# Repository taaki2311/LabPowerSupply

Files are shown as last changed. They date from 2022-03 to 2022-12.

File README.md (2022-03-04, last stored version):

# ECE_492-3_Topic_1

This git repository is for ECE/RS 492/3 Topic 1: Lab Power Supply in Spring to Fall 2022.

## Getting started

To make it easy for you to get started with GitLab, here's a list of recommended next steps.

Already a pro? Just edit this README.md and make it your own. Want to make it easy? [Use the template at the bottom](#editing-this-readme)!

## Add your files

- [ ] [Create](https://docs.gitlab.com/ee/user/project/repository/web_editor.html#create-a-file) or [upload](https://docs.gitlab.com/ee/user/project/repository/web_editor.html#upload-a-file) files
- [ ] [Add files using the command line](https://docs.gitlab.com/ee/gitlab-basics/add-file.html#add-a-file-using-the-command-line) or push an existing Git repository with the following command:

```
cd existing_repo
git remote add origin https://git.gmu.edu/tsingh8/ece_492-3_topic_1.git
git branch -M main
git push -uf origin main
```

## Integrate with your tools

- [ ] [Set up project integrations](https://git.gmu.edu/tsingh8/ece_492-3_topic_1/-/settings/integrations)

## Collaborate with your team

- [ ] [Invite team members and collaborators](https://docs.gitlab.com/ee/user/project/members/)
- [ ] [Create a new merge request](https://docs.gitlab.com/ee/user/project/merge_requests/creating_merge_requests.html)
- [ ] [Automatically close issues from merge requests](https://docs.gitlab.com/ee/user/project/issues/managing_issues.html#closing-issues-automatically)
- [ ] [Enable merge request approvals](https://docs.gitlab.com/ee/user/project/merge_requests/approvals/)
- [ ] [Automatically merge when pipeline succeeds](https://docs.gitlab.com/ee/user/project/merge_requests/merge_when_pipeline_succeeds.html)

## Test and Deploy

Use the built-in continuous integration in GitLab.

- [ ] [Get started with GitLab CI/CD](https://docs.gitlab.com/ee/ci/quick_start/index.html)
- [ ] [Analyze your code for known vulnerabilities with Static Application Security Testing(SAST)](https://docs.gitlab.com/ee/user/application_security/sast/)
- [ ] [Deploy to Kubernetes, Amazon EC2, or Amazon ECS using Auto Deploy](https://docs.gitlab.com/ee/topics/autodevops/requirements.html)
- [ ] [Use pull-based deployments for improved Kubernetes management](https://docs.gitlab.com/ee/user/clusters/agent/)
- [ ] [Set up protected environments](https://docs.gitlab.com/ee/ci/environments/protected_environments.html)

***

# Editing this README

When you're ready to make this README your own, just edit this file and use the handy template below (or feel free to structure it however you want - this is just a starting point!).  Thank you to [makeareadme.com](https://www.makeareadme.com/) for this template.

## Suggestions for a good README
Every project is different, so consider which of these sections apply to yours. The sections used in the template are suggestions for most open source projects. Also keep in mind that while a README can be too long and detailed, too long is better than too short. If you think your README is too long, consider utilizing another form of documentation rather than cutting out information.

## Name
Choose a self-explaining name for your project.

## Description
Let people know what your project can do specifically. Provide context and add a link to any reference visitors might be unfamiliar with. A list of Features or a Background subsection can also be added here. If there are alternatives to your project, this is a good place to list differentiating factors.

## Badges
On some READMEs, you may see small images that convey metadata, such as whether or not all the tests are passing for the project. You can use Shields to add some to your README. Many services also have instructions for adding a badge.

## Visuals
Depending on what you are making, it can be a good idea to include screenshots or even a video (you'll frequently see GIFs rather than actual videos). Tools like ttygif can help, but check out Asciinema for a more sophisticated method.

## Installation
Within a particular ecosystem, there may be a common way of installing things, such as using Yarn, NuGet, or Homebrew. However, consider the possibility that whoever is reading your README is a novice and would like more guidance. Listing specific steps helps remove ambiguity and gets people to using your project as quickly as possible. If it only runs in a specific context like a particular programming language version or operating system or has dependencies that have to be installed manually, also add a Requirements subsection.

## Usage
Use examples liberally, and show the expected output if you can. It's helpful to have inline the smallest example of usage that you can demonstrate, while providing links to more sophisticated examples if they are too long to reasonably include in the README.

## Support
Tell people where they can go to for help. It can be any combination of an issue tracker, a chat room, an email address, etc.

## Roadmap
If you have ideas for releases in the future, it is a good idea to list them in the README.

## Contributing
State if you are open to contributions and what your requirements are for accepting them.

For people who want to make changes to your project, it's helpful to have some documentation on how to get started. Perhaps there is a script that they should run or some environment variables that they need to set. Make these steps explicit. These instructions could also be useful to your future self.

You can also document commands to lint the code or run tests. These steps help to ensure high code quality and reduce the likelihood that the changes inadvertently break something. Having instructions for running tests is especially helpful if it requires external setup, such as starting a Selenium server for testing in a browser.

## Authors and acknowledgment
Show your appreciation to those who have contributed to the project.

## License
For open source projects, say how it is licensed.

## Project status
If you have run out of energy or time for your project, put a note at the top of the README saying that development has slowed down or stopped completely. Someone may choose to fork your project or volunteer to step in as a maintainer or owner, allowing your project to keep going. You can also make an explicit request for maintainers.

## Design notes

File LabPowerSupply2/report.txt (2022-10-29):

Plotted to 'C:\Users\Krotain\Documents\git\493\ece_492-3_topic_1\LabPowerSupply\Gerbers\LabPowerSupply-Fsig_Cu.gbr'.
Plotted to 'C:\Users\Krotain\Documents\git\493\ece_492-3_topic_1\LabPowerSupply\Gerbers\LabPowerSupply-pwr_Cu.gbr'.
Plotted to 'C:\Users\Krotain\Documents\git\493\ece_492-3_topic_1\LabPowerSupply\Gerbers\LabPowerSupply-gnd_Cu.gbr'.
Plotted to 'C:\Users\Krotain\Documents\git\493\ece_492-3_topic_1\LabPowerSupply\Gerbers\LabPowerSupply-Bsig_Cu.gbr'.
Plotted to 'C:\Users\Krotain\Documents\git\493\ece_492-3_topic_1\LabPowerSupply\Gerbers\LabPowerSupply-F_Paste.gbr'.
Plotted to 'C:\Users\Krotain\Documents\git\493\ece_492-3_topic_1\LabPowerSupply\Gerbers\LabPowerSupply-B_Paste.gbr'.
Plotted to 'C:\Users\Krotain\Documents\git\493\ece_492-3_topic_1\LabPowerSupply\Gerbers\LabPowerSupply-F_Silkscreen.gbr'.
Plotted to 'C:\Users\Krotain\Documents\git\493\ece_492-3_topic_1\LabPowerSupply\Gerbers\LabPowerSupply-B_Silkscreen.gbr'.
Plotted to 'C:\Users\Krotain\Documents\git\493\ece_492-3_topic_1\LabPowerSupply\Gerbers\LabPowerSupply-F_Mask.gbr'.
Plotted to 'C:\Users\Krotain\Documents\git\493\ece_492-3_topic_1\LabPowerSupply\Gerbers\LabPowerSupply-B_Mask.gbr'.
Plotted to 'C:\Users\Krotain\Documents\git\493\ece_492-3_topic_1\LabPowerSupply\Gerbers\LabPowerSupply-Edge_Cuts.gbr'.
Created Gerber job file 'C:\Users\Krotain\Documents\git\493\ece_492-3_topic_1\LabPowerSupply\Gerbers\LabPowerSupply-job.gbrjob'.
Info: Done.

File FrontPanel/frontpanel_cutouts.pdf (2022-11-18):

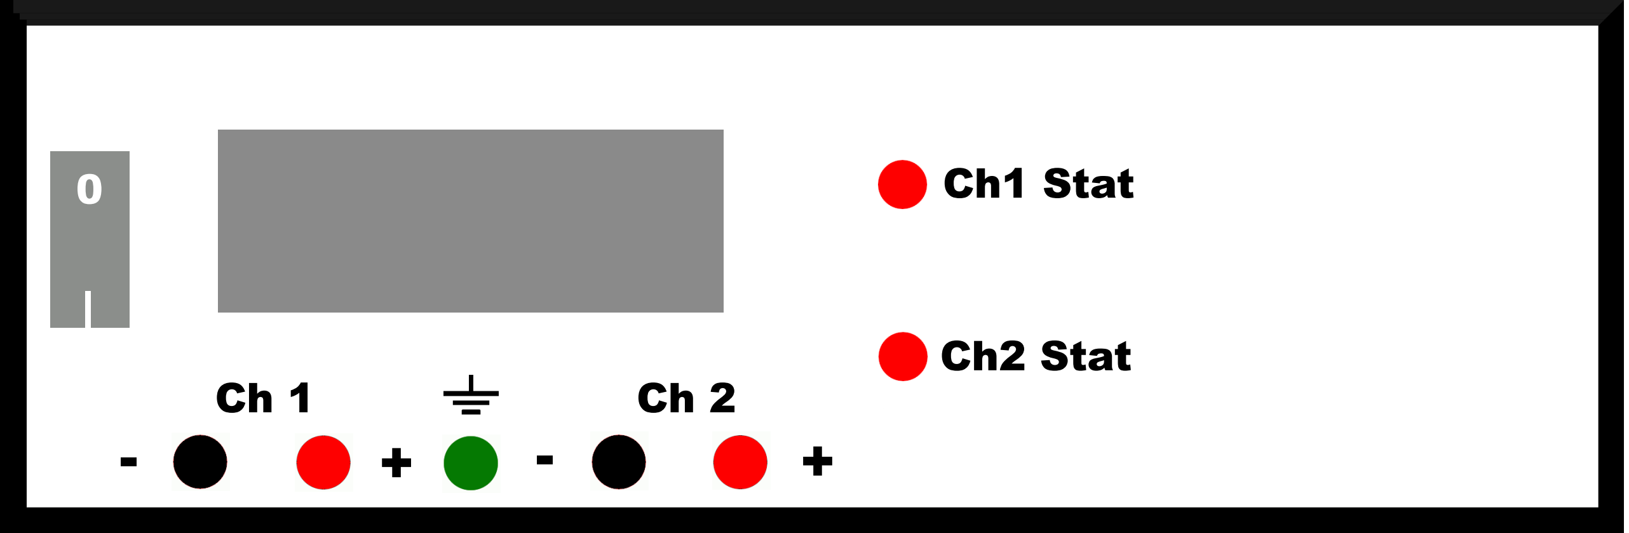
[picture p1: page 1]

- | + | - | +

0

Ch 1 | Ch 2

Ch2 Stat

Ch1 Stat

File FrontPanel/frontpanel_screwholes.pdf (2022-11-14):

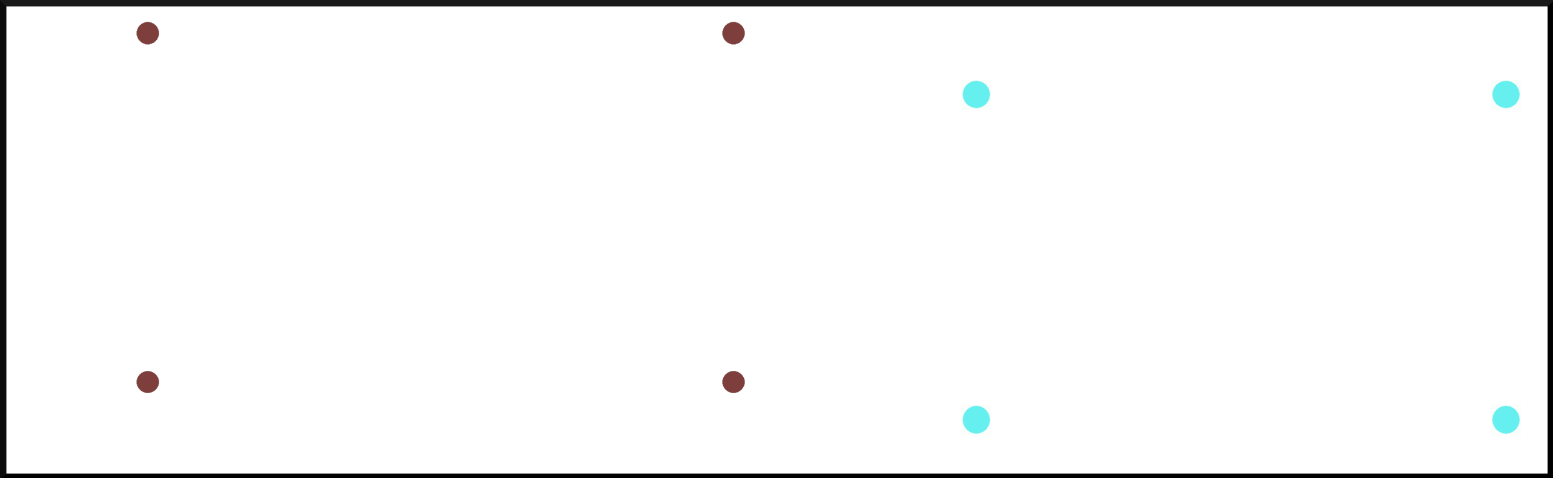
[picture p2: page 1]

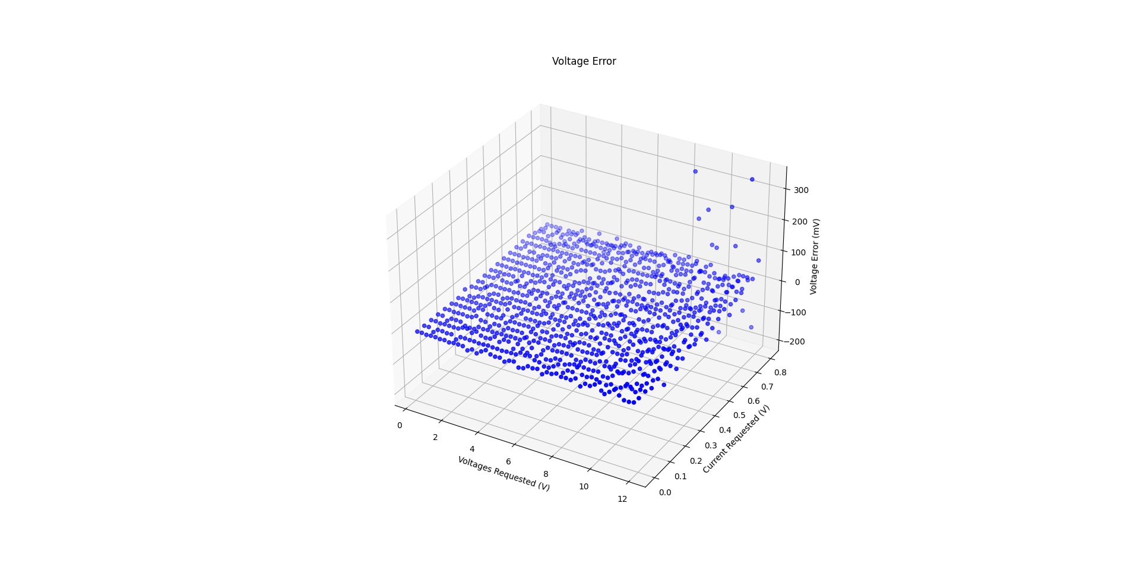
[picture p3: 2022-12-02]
Plots/voltage_plot.png

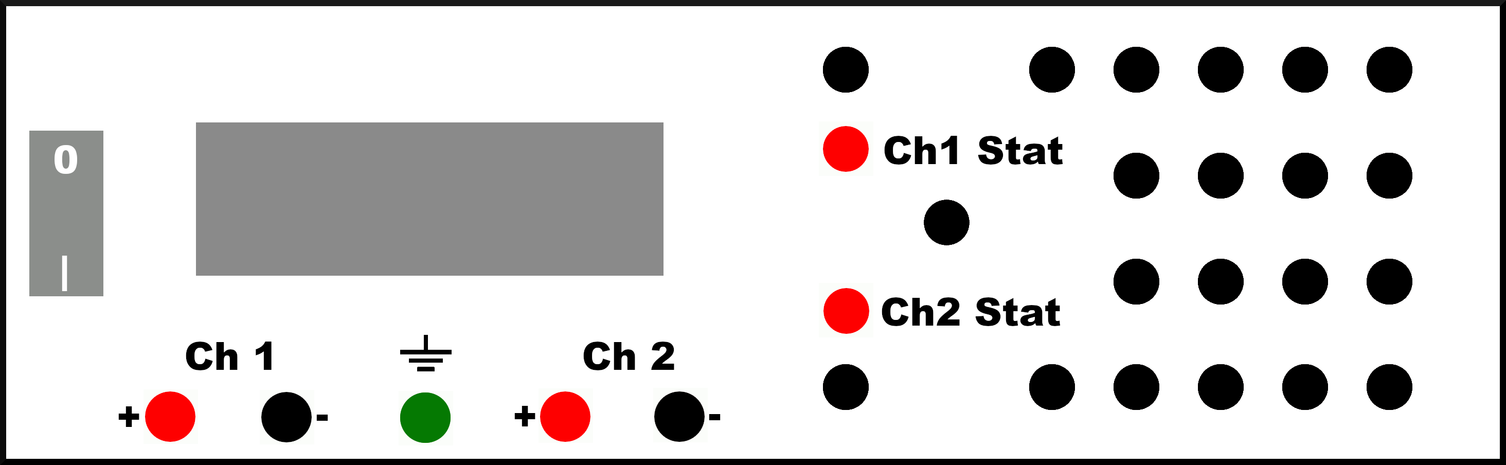
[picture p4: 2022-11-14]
FrontPanel/frontpanel_cutouts.png

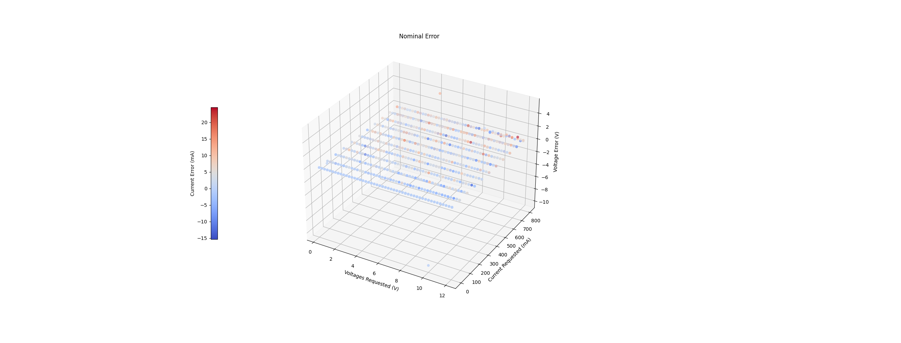
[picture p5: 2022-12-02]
Plots/combined_plot.png

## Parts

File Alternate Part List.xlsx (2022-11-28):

Part(*=Similar) | Quantity | $/1 | $/1000 | Total | Value | Tolerance | Size/Package | Link | Running Total
PMEG3020CEP,115 | 8 | 0.49 | 0.152 | 1.216 | 2A 30V | n/a | SOD-128-2 | https://www.digikey.com/en/products/detail/nexperia-usa-inc/PMEG3020CEP-115/2119870 | 106.07417
GS2A-LTP | 10 | 0.4 | 0.079 | 0.79 | 2A 50V | n/a | DO-214AC-2 | https://www.mouser.com/ProductDetail/Micro-Commercial-Components-MCC/GS2A-LTP
UVR1E682MHD | 4 | 2.47 | 1.01 | 4.04 | 6.8mF | 20% | 18x35.5x7.5mm | https://www.mouser.com/ProductDetail/Nichicon/UVR1E682MHD?qs=sGAEpiMZZMvwFf0viD3Y3UQjCBAmXhuzNEsRvpP9m3M%3D
UVZ1E102MPD | 2 | 0.78 | 0.22874 | 0.45748 | 1mF | 20% | 10x20x5mm | https://www.digikey.com/en/products/detail/nichicon/UVZ1E102MPD/589046
A750KK107M1EAAE040 | 2 | 0.62 | 0.18 | 0.36 | 100uf | 20% | 8x8x3.5mm Rad | https://www.mouser.com/ProductDetail/KEMET/A750KK107M1EAAE040?qs=M6jHmRuQorXMeyrpWCoqNA%3D%3D
CL32A226KAJNNNE | 12 | 0.44 | 0.12888 | 1.54656 | 22uf | 10% | 1210 | https://www.digikey.com/en/products/detail/samsung-electro-mechanics/CL32A226KAJNNNE/3886759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
CL31A106MAHNNNE | 6 | 0.19 | 0.03713 | 0.22278 | 10uf | 10% | 1206 | https://www.digikey.com/en/products/detail/samsung-electro-mechanics/CL31A106MAHNNNE/3886839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
CL21A475KAQNNNG | 2 | 0.1 | 0.01984 | 0.03968 | 4.7uf | 10% | 0805 | https://www.digikey.com/en/products/detail/samsung-electro-mechanics/CL21A475KAQNNNG/3894439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
CL21A225KAFNNNG | 2 | 0.12 | 0.02331 | 0.04662 | 2.2uf | 10% | 0805 | https://www.digikey.com/en/products/detail/samsung-electro-mechanics/CL21A225KAFNNNG/3894427
CL10A105KA8NNNC | 9 | 0.1 | 0.00786 | 0.07074 | 1uf | 10% | 0603 | https://www.digikey.com/en/products/detail/samsung-electro-mechanics/CL10A105KA8NNNC/3886760
CL10B104KB8NNWC | 17 | 0.1 | 0.00467 | 0.07939 | 100nf | 10% | 0603 | https://www.digikey.com/en/products/detail/samsung-electro-mechanics/CL10B104KB8NNWC/3887593
CL10B223KB8NNNC | 2 | 0.1 | 0.00819 | 0.01638 | 22nf | 10% | 0603 | https://www.digikey.com/en/products/detail/samsung-electro-mechanics/CL10B223KB8NNNC/3886762
0603B221K500CT | 2 | 0.1 | 0.00667 | 0.01334 | 220pf | 10% | 0603 | https://www.digikey.com/en/products/detail/walsin-technology-corporation/0603B221K500CT/9354904
CML0603C0G200JT50V | 6 | 0.1 | 0.00889 | 0.05334 | 20pf | 5% | 0603 | https://www.digikey.com/en/products/detail/stackpole-electronics-inc/CML0603C0G200JT50V/10659974
SN74HC04DBRG4 | 2 | 0.46 | 0.142 | 0.284 | n/a | n/a | SSOP-14 | https://www.mouser.com/ProductDetail/Texas-Instruments/SN74HC04DBRG4?qs=XQzc%252BbSrk58m%252Bx0j7t4flA%3D%3D
6N137S-TA1 | 2 | 0.84 | 0.283 | 0.566 | n/a | n/a | SMD-8 | https://www.mouser.com/ProductDetail/Lite-On/6N137S-TA1?qs=PByDJ0nQNwrChwHSrgNi1w%3D%3D
LM324DR | 2 | 0.38 | 0.117 | 0.234 | n/a | n/a | SOIC-14 | https://www.mouser.com/ProductDetail/Texas-Instruments/LM324DR?qs=KaAwwOlwaps1n%2FWkYDapEg%3D%3D
INA180A1 | 2 | 0.51 | 0.19642 | 0.39284 | n/a | n/a | SOT-23-5 | https://www.digikey.com/en/products/detail/texas-instruments/INA180A1IDBVR/8132986
PJA3404_R1_00001 | 6 | 0.38 | 0.08197 | 0.49182 | n/a | n/a | SOT-23-5 | https://www.digikey.com/en/products/detail/panjit-international-inc/PJA3404-R1-00001/14660647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
FMMT495 | 2 | 0.4 | 0.124 | 0.248 | n/a | n/a | SOT-23-3 | https://www.mouser.com/ProductDetail/Diodes-Incorporated/FMMT495TA?qs=YwPsRIUVAOcuV4OIGitV8Q%3D%3D
PTS181224V075 | 2 | 0.59 | 0.285 | 3083et | 0.2Ohm | n/a | 1812 | https://www.mouser.com/ProductDetail/576-1812L110-24DR
AP63205WU-7 | 2 | 0.91 | 0.38737 | 0.77474 | n/a | n/a | TSOT-26-6 | https://www.digikey.com/en/products/detail/diodes-incorporated/AP63205WU-7/9858424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
LP2950CDT-3.3RKG | 2 | 0.75 | 0.32139 | 0.64278 | n/a | n/a | TO-252-3 | https://www.digikey.com/en/products/detail/onsemi/LP2950CDT-3-3RKG/1476904
LT3080EDD | 2 | 6.41 | 7.29 | 14.58 | n/a | n/a | DFN-8 | https://www.mouser.com/ProductDetail/Analog-Devices/LT3080EDD-1TRPBF?qs=hVkxg5c3xu%2F3H2mzAs8Yaw%3D%3D
L6902D | 2 | 3.44 | 1.96 | 3.92 | n/a | n/a | SOIC-8 | https://www.mouser.com/ProductDetail/STMicroelectronics/L6902D?qs=Yc96klrMi5L2iIsse6YmdQ%3D%3D
Enclosure | 1 | 15.95 | 12.95 | 12.95 | n/a | n/a | n/a | https://www.jameco.com/z/SY0207-R-Jameco-Valuepro-Metal-Enclosure-2-Piece-7-5-x-9-8-x-3-2-Gloss-Black-and-Ivory_209358.html
20x4 Character Display | 1 | 12.95 | 10.95 | 10.95 | n/a | n/a | n/a | https://www.jameco.com/z/SIC2004A-BLWIT-Jameco-Valuepro-20x4-Character-LCD-Module-Parallel-Display-with-I2C-Module-Blue-Backlight-for-Arduino_2304015.html
USB4125-GF-A | 1 | 0.65 | 0.332 | 0.332 | n/a | n/a | n/a | https://www.mouser.com/ProductDetail/GCT/USB4125-GF-A?qs=KUoIvG%2F9IlaIQ4zBJ6gLeA%3D%3D
STM32L152RBT6A | 1 | 8.06 | 4.51 | 4.51 | n/a | n/a | LQFP-64 | https://www.mouser.com/ProductDetail/STMicroelectronics/STM32L152RBT6A?qs=DqCdCwOw4%2F646g2lv17dkw%3D%3D
STM32L100C6U6A | 1 | 5.57 | 2.95 | 2.95 | n/a | n/a | UFQFPN-48 | https://www.mouser.com/ProductDetail/STMicroelectronics/STM32L100C6U6A?qs=9MuLHSklicr37J4PyR0bYg%3D%3D
ATS08ASM-1 | 2 | 0.29 | 0.153 | 0.306 | 8MHz | n/a | HC-49/US-SM | https://www.mouser.com/ProductDetail/CTS-Electronic-Components/ATS08ASM-1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
FS24-1500-C2 | 1 | 17.1 | 14.38 | 14.38 | n/a | n/a | Big | https://www.mouser.com/ProductDetail/553-FS24-1500-C2
CR75NP-220KC | 2 | 1.08 | 0.4956 | 0.9912 | 22uh | 10% | Nonstandard | https://www.digikey.com/en/products/detail/sumida-america-inc/CR75NP-220KC/1059617
CDMC6D28NP-4R7MC | 2 | 1.25 | 0.57288 | 1.14576 | 4.7uh | 20% | Nonstandard | https://www.digikey.com/en/products/detail/sumida-america-inc/CDMC6D28NP-4R7MC/2620811
KDV06FR100ET | 2 | 0.26 | 0.036 | 0.072 | 100mOhm | 1% | 0603 | https://www.mouser.com/ProductDetail/Ohmite/KDV06FR100ET?qs=l4Gc20tDgJJaN5LrlJmh%2FQ%3D%3D
KDV12FR150ET | 2 | 0.31 | 0.044 | 0.088 | 150mOhm | 1% | 1206 | https://www.mouser.com/ProductDetail/Ohmite/KDV12FR150ET?qs=l4Gc20tDgJJL5FQR0zIa1w%3D%3D
WR06X1002FTL | 8 | 0.1 | 0.00191 | 0.01528 | 10kOhm | 1% | 0603 | https://www.digikey.com/en/products/detail/walsin-technology-corporation/WR06X1002FTL/13241983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
RMCF0603FT5K10 | 8 | 0.14 | 0.021 | 0.168 | 5.1kOhm | 1% | 0603 | https://www.digikey.com/en/products/detail/stackpole-electronics-inc/RMCF0603FT5K10/1760908
WR06X4701FTL | 2 | 0.1 | 0.00191 | 0.00382 | 4.7kOhm | 1% | 0603 | https://www.digikey.com/en/products/detail/walsin-technology-corporation/WR06X4701FTL/13240840
RMCF0603FT2K00 | 20 | 0.1 | 0.00273 | 0.0546 | 2kOhm | 1% | 0603 | https://www.digikey.com/en/products/detail/stackpole-electronics-inc/RMCF0603FT2K00/1761334
RMCF0603FT1K20 | 6 | 0.1 | 0.00273 | 0.01638 | 1.2kOhm | 1% | 0603 | https://www.digikey.com/en/products/detail/stackpole-electronics-inc/RMCF0603FT1K20/1761134
WR06X1001FTL | 32 | 0.1 | 0.00191 | 0.06112 | 1kOhm | 1% | 0603 | https://www.digikey.com/en/products/detail/walsin-technology-corporation/WR06X1001FTL/13241294
WR06X4700FTL | 2 | 0.1 | 0.00191 | 0.00382 | 470Ohm | 1% | 0603 | https://www.digikey.com/en/products/detail/walsin-technology-corporation/WR06X4700FTL/13240646
WR06X1000FTL | 2 | 0.1 | 0.00191 | 0.00382 | 100Ohm | 1% | 0603 | https://www.digikey.com/en/products/detail/walsin-technology-corporation/WR06X1000FTL/13240850
RMCF0603FT22R0 | 2 | 0.1 | 0.00273 | 0.00546 | 22Ohm | 1% | 0603 | https://www.digikey.com/en/products/detail/stackpole-electronics-inc/RMCF0603FT22R0/1760726
PEC11H-4015F-S0016* | 1 | 2.69 | 1.62 | 1.62 | n/a | n/a | n/a | https://www.mouser.com/ProductDetail/Bourns/PEC11H-4015F-S0016?qs=7MVldsJ5UazZ6nkvCEo76Q%3D%3D
TS13-1212-73-BK-260-D | 22 | 0.27 | 0.159 | 3.498 | n/a | n/a | n/a | https://www.mouser.com/ProductDetail/CUI-Devices/TS13-1212-73-BK-260-D?qs=t7xnP681wgVDgyvNlgHoxQ%3D%3D
150060AS75003 | 4 | 0.35 | 0.181 | 0.724 | n/a | n/a | n/a | https://www.digikey.com/en/products/detail/w%C3%BCrth-elektronik/150060AS75003/16022162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
552-* | 5 | 2.36 | 1.63 | 8.15 | n/a | n/a | n/a | https://www.mouser.com/ProductDetail/Deltron/552-0400-GRN?qs=lj71xN7SzAIkm5eVvW23fw%3D%3D
101-166 | 2 | 0.37 | 0.1764 | 0.3528 | n/a | n/a | n/a | https://www.digikey.com/en/products/detail/on-shore-technology-inc/101-166/2794214
302-S161 | 2 | 0.42 | 0.19661 | 0.39322 | n/a | n/a | n/a | https://www.digikey.com/en/products/detail/on-shore-technology-inc/302-S161/2794234
3365/16 300 | 1 | 0.82 | 0.4818 | 0.4818 | n/a | n/a | n/a | https://www.digikey.com/en/products/detail/3m/3365-16-300/9478306
Front Panel PCB | 1/1000 | 7.3 | 389.3 | 3.893 | n/a | n/a | n/a
Main PCB | 1/1000 | 39.9 | 1447.6 | 1.4476 | n/a | n/a | n/a
Front Panel Laminate | 1 | 2 | 2 | 2 | n/a | n/a | n/a
Front Panel Switch | 1 | 1.94 | 1.27 | 1.27 | n/a | n/a | n/a | https://www.mouser.com/ProductDetail/Carling-Technologies/LRA211-RS-B-125N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
AC Power Plug | 1 | 1.49 | 1.15 | 1.15 | n/a | n/a | n/a | https://www.jameco.com/z/JR-101-F-Jameco-Valuepro-Receptacle-Male-10A-250VoltFused-Fast-On-UL-CSA-Vde_265528.html
Front Panel Keys | 1 | 1 | 1 | 1 | n/a | n/a | n/a

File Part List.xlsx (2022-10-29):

Part(*=Similar) | Quantity | $/1 | $/1000 | Total | Value | Tolerance | Size/Package | Link | Running Total
PMEG3020CEP,115 | 8 | 0.5 | 0.159 | 1.272 | 2A 30V | n/a | SOD-128-2 | https://www.mouser.com/ProductDetail/Nexperia/PMEG3020CEP115?qs=LMSg3oBIm%2Fgs8Me4yQ8MUQ%3D%3D | 99.558452
GS2A-LTP | 10 | 0.4 | 0.079 | 0.79 | 2A 50V | n/a | DO-214AC-2 | https://www.mouser.com/ProductDetail/Micro-Commercial-Components-MCC/GS2A-LTP
UVR1E682MHD | 4 | 2.47 | 1.01 | 4.04 | 6.8mF | 20% | 18x35.5x7.5mm | https://www.mouser.com/ProductDetail/Nichicon/UVR1E682MHD?qs=sGAEpiMZZMvwFf0viD3Y3UQjCBAmXhuzNEsRvpP9m3M%3D
UVZ1E102MPD | 2 | 0.63 | 0.437 | 0.874 | 1mF | 20% | 10x20x5mm | https://www.mouser.com/ProductDetail/Nichicon/UVZ1E102MPD?qs=EuSGJ%252B0eAhAp2LxNcdtdzw%3D%3D
870025574003 | 0 | 0.83 | 0.547 | 0 | 68uf | 20% | 8x8x3.5mm Rad | https://www.mouser.com/ProductDetail/Wurth-Elektronik/870025574003?qs=0KOYDY2FL29sdAoPfg4aVQ%3D%3D
A750KK107M1EAAE040 | 2 | 0.62 | 0.18 | 0.36 | 100uf | 20% | 8x8x3.5mm Rad | https://www.mouser.com/ProductDetail/Wurth-Elektronik/870025574003?qs=0KOYDY2FL29sdAoPfg4aVQ%3D%3D
CL21A226MAYNNNE | 12 | 0.6 | 0.17 | 2.04 | 22uf | 10% | 1210 | https://www.mouser.com/ProductDetail/Samsung-Electro-Mechanics/CL32B226KAJNNNE?qs=349EhDEZ59oxUqah7LWaWw%3D%3D
CL31B106KAHNFNE | 6 | 0.23 | 0.048 | 0.288 | 10uf | 10% | 1206 | https://www.mouser.com/ProductDetail/Samsung-Electro-Mechanics/CL31B106KAHNFNE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
CL21B475KAFNNNE | 2 | 0.43 | 0.126 | 0.252 | 4.7uf | 10% | 0805 | https://www.mouser.com/ProductDetail/Samsung-Electro-Mechanics/CL21B475KAFNNNE?qs=fer0DVZjnG76MxvRzgkzzw%3D%3D
CL21B225KAFNNNG | 2 | 0.13 | 0.025 | 0.05 | 2.2uf | 10% | 0805 | https://www.mouser.com/ProductDetail/Samsung-Electro-Mechanics/CL21B225KAFNNNG?qs=yOVawPpwOwljM4cRphaUPg%3D%3D
CL10B105KA8NFNC | 9 | 0.1 | 0.011 | 0.099 | 1uf | 10% | 0603 | https://www.mouser.com/ProductDetail/Samsung-Electro-Mechanics/CL10B105KA8NFNC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
CL10B104KA8NNNC | 17 | 0.1 | 0.007 | 0.119 | 100nf | 10% | 0603 | https://www.mouser.com/ProductDetail/Samsung-Electro-Mechanics/CL10B104KA8NNNC?qs=349EhDEZ59rmu3pGeZXx0A%3D%3D
CL10B223KB85PNC | 2 | 0.1 | 0.017 | 0.034 | 22nf | 10% | 0603 | https://www.mouser.com/ProductDetail/Samsung-Electro-Mechanics/CL10B223KB85PNC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
CL03B221KA3NNNC | 2 | 0.11 | 0.022 | 0.044 | 220pf | 10% | 0603 | https://www.mouser.com/ProductDetail/Samsung-Electro-Mechanics/CL03B221KA3NNNC?qs=47mY1nHWefTe9eNIIKkdYQ%3D%3D
CL10C200JB8NNNC | 6 | 0.1 | 0.011 | 0.066 | 20pf | 5% | 0603 | https://www.mouser.com/ProductDetail/Samsung-Electro-Mechanics/CL10C200JB8NNNC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
SN74HC04DBRG4 | 2 | 0.46 | 0.142 | 0.284 | n/a | n/a | SSOP-14 | https://www.mouser.com/ProductDetail/Texas-Instruments/SN74HC04DBRG4?qs=XQzc%252BbSrk58m%252Bx0j7t4flA%3D%3D
6N137S-TA1 | 2 | 0.84 | 0.283 | 0.566 | n/a | n/a | SMD-8 | https://www.mouser.com/ProductDetail/Lite-On/6N137S-TA1?qs=PByDJ0nQNwrChwHSrgNi1w%3D%3D
LM324DR | 2 | 0.38 | 0.117 | 0.234 | n/a | n/a | SOIC-14 | https://www.mouser.com/ProductDetail/Texas-Instruments/LM324DR?qs=KaAwwOlwaps1n%2FWkYDapEg%3D%3D
INA180A1 | 2 | 1.05 | 0.4784 | 0.9568 | n/a | n/a | SOT-23-5 | https://www.digikey.com/en/products/detail/texas-instruments/INA180A1IDBVT/7219027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
PJA3404_R1_00001 | 6 | 0.37 | 0.082 | 0.492 | n/a | n/a | SOT-23-5 | https://www.mouser.com/ProductDetail/Panjit/PJA3404_R1_00001?qs=sPbYRqrBIVkiUO9ZInE3tw%3D%3D
FMMT495 | 2 | 0.4 | 0.124 | 0.248 | n/a | n/a | SOT-23-3 | https://www.mouser.com/ProductDetail/Diodes-Incorporated/FMMT495TA?qs=YwPsRIUVAOcuV4OIGitV8Q%3D%3D
PTS181224V075 | 2 | 0.21 | 0.114 | 0.228 | 0.29Ohm | n/a | 1812 | https://www.mouser.com/ProductDetail/Bussmann-Eaton/PTS181224V075?qs=QmibqUXyDhQsWMUFkSWVRg%3D%3D
AP63205WU-7 | 2 | 0.91 | 0.388 | 0.776 | n/a | n/a | TSOT-26-6 | https://www.mouser.com/ProductDetail/Diodes-Incorporated/AP63205WU-7?qs=u16ybLDytRZtkj8PzdWCOw%3D%3D
LP2950CDT-3.3RKG | 2 | 0.76 | 0.328 | 0.656 | n/a | n/a | TO-252-3 | https://www.mouser.com/ProductDetail/onsemi/LP2950CDT-3.3RKG?qs=2OtswVQKCOGjJvIdedTxCw%3D%3D
LT3080EDD | 2 | 6.41 | 3.41 | 6.82 | n/a | n/a | DFN-8 | https://www.mouser.com/ProductDetail/Analog-Devices/LT3080EDD-1TRPBF?qs=hVkxg5c3xu%2F3H2mzAs8Yaw%3D%3D
L6902D | 2 | 3.44 | 1.96 | 3.92 | n/a | n/a | SOIC-8 | https://www.mouser.com/ProductDetail/STMicroelectronics/L6902D?qs=Yc96klrMi5L2iIsse6YmdQ%3D%3D
Enclosure | 1 | 15.95 | 12.95 | 12.95 | n/a | n/a | n/a | https://www.jameco.com/z/SY0207-R-Jameco-Valuepro-Metal-Enclosure-2-Piece-7-5-x-9-8-x-3-2-Gloss-Black-and-Ivory_209358.html
20x4 Character Display | 1 | 12.95 | 10.95 | 10.95 | n/a | n/a | n/a | https://www.jameco.com/z/SIC2004A-BLWIT-Jameco-Valuepro-20x4-Character-LCD-Module-Parallel-Display-with-I2C-Module-Blue-Backlight-for-Arduino_2304015.html
USB4125-GF-A | 1 | 0.65 | 0.332 | 0.332 | n/a | n/a | n/a | https://www.mouser.com/ProductDetail/GCT/USB4125-GF-A?qs=KUoIvG%2F9IlaIQ4zBJ6gLeA%3D%3D
STM32L152RBT6A | 1 | 8.06 | 4.51 | 4.51 | n/a | n/a | LQFP-64 | https://www.mouser.com/ProductDetail/STMicroelectronics/STM32L152RBT6A?qs=DqCdCwOw4%2F646g2lv17dkw%3D%3D
STM32L100C6U6A | 1 | 5.57 | 2.95 | 2.95 | n/a | n/a | UFQFPN-48 | https://www.mouser.com/ProductDetail/STMicroelectronics/STM32L100C6U6A?qs=9MuLHSklicr37J4PyR0bYg%3D%3D
ATS08ASM-1 | 2 | 0.29 | 0.153 | 0.306 | 8MHz | n/a | HC-49/US-SM | https://www.mouser.com/ProductDetail/CTS-Electronic-Components/ATS08ASM-1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
FS24-800-C2 | 1 | 16.5 | 9.82 | 9.82 | n/a | n/a | Big | https://www.mouser.com/ProductDetail/Triad-Magnetics/FS24-800-C2?qs=b1anAsPanWysxDNUFWmxRA%3D%3D
CR75NP-220KC | 2 | 1.08 | 0.4956 | 0.9912 | 22uh | 10% | Nonstandard | https://www.digikey.com/en/products/detail/sumida-america-inc/CR75NP-220KC/1059617
CDMC6D28NP-4R7MC | 2 | 1.25 | 0.57288 | 1.14576 | 4.7uh | 20% | Nonstandard | https://www.digikey.com/en/products/detail/sumida-america-inc/CDMC6D28NP-4R7MC/2620811
KDV06FR180ET | 2 | 0.26 | 0.036 | 0.072 | 180mOhm | 1% | 0603 | https://www.mouser.com/ProductDetail/Ohmite/KDV06FR180ET?qs=l4Gc20tDgJLuG9Oc1mkpPg%3D%3D
KDV12FR300ET | 2 | 0.31 | 0.044 | 0.088 | 300mOhm | 1% | 1206 | https://www.mouser.com/ProductDetail/Ohmite/KDV12FR300ET?qs=l4Gc20tDgJJqdOINs5xdYg%3D%3D
SDR03EZPF1002 | 8 | 0.14 | 0.021 | 0.168 | 10kOhm | 1% | 0603 | https://www.mouser.com/ProductDetail/ROHM-Semiconductor/SDR03EZPF1002?qs=byeeYqUIh0Mlr2mre8duxQ%3D%3D
ESR03EZPF5101 | 8 | 0.14 | 0.021 | 0.168 | 5.1kOhm | 1% | 0603 | https://www.mouser.com/ProductDetail/ROHM-Semiconductor/ESR03EZPF5101?qs=493kPxzlxfITg5G1s39ZCA%3D%3D
ESR03EZPF4701 | 2 | 0.14 | 0.021 | 0.042 | 4.7kOhm | 1% | 0603 | https://www.mouser.com/ProductDetail/ROHM-Semiconductor/ESR03EZPF4701?qs=493kPxzlxfL2NnaeJoZB2Q%3D%3D
ESR03EZPF2001 | 20 | 0.14 | 0.024 | 0.48 | 2kOhm | 1% | 0603 | https://www.mouser.com/ProductDetail/ROHM-Semiconductor/ESR03EZPF2001?qs=493kPxzlxfIsacc9Eh0USA%3D%3D
ESR03EZPF1201 | 6 | 0.14 | 0.021 | 0.126 | 1.2kOhm | 1% | 0603 | https://www.mouser.com/ProductDetail/ROHM-Semiconductor/ESR03EZPF1201?qs=493kPxzlxfIq0F4ql8poBA%3D%3D
ESR03EZPF1001 | 32 | 0.15 | 0.021 | 0.672 | 1kOhm | 1% | 0603 | https://www.mouser.com/ProductDetail/ROHM-Semiconductor/ESR03EZPF1001?qs=DyUWGjl%252BcVtUAf3p1rg3iQ%3D%3D
ESR03EZPF4700 | 2 | 0.16 | 0.023 | 0.046 | 470Ohm | 1% | 0603 | https://www.mouser.com/ProductDetail/ROHM-Semiconductor/ESR03EZPF4700?qs=DyUWGjl%252BcVsZQGp8SgvEfA%3D%3D
ESR03EZPF1000 | 2 | 0.14 | 0.024 | 0.048 | 100Ohm | 1% | 0603 | https://www.mouser.com/ProductDetail/ROHM-Semiconductor/ESR03EZPF1000?qs=493kPxzlxfJdLkJZpX4ByA%3D%3D
ESR03EZPF22R0 | 2 | 0.16 | 0.023 | 0.046 | 22Ohm | 1% | 0603 | https://www.mouser.com/ProductDetail/ROHM-Semiconductor/ESR03EZPF22R0?qs=493kPxzlxfL2v77xEtzYQA%3D%3D
PEC11H-4015F-S0016* | 1 | 2.69 | 1.62 | 1.62 | n/a | n/a | n/a | https://www.mouser.com/ProductDetail/Bourns/PEC11H-4015F-S0016?qs=7MVldsJ5UazZ6nkvCEo76Q%3D%3D
TS13-1212-73-BK-260-D | 22 | 0.27 | 0.159 | 3.498 | n/a | n/a | n/a | https://www.mouser.com/ProductDetail/CUI-Devices/TS13-1212-73-BK-260-D?qs=t7xnP681wgVDgyvNlgHoxQ%3D%3D
150060AS75003 | 4 | 0.35 | 0.226 | 0.904 | n/a | n/a | n/a | https://www.mouser.com/ProductDetail/Wurth-Elektronik/150060AS75003?qs=Li%252BoUPsLEntY15YiEuZJ2w%3D%3D
552-* | 5 | 2.36 | 1.63 | 8.15 | n/a | n/a | n/a | https://www.mouser.com/ProductDetail/Deltron/552-0400-GRN?qs=lj71xN7SzAIkm5eVvW23fw%3D%3D
101-166 | 2 | 0.37 | 0.1764 | 0.3528 | n/a | n/a | n/a | https://www.digikey.com/en/products/detail/on-shore-technology-inc/101-166/2794214
302-S161 | 2 | 0.42 | 0.19661 | 0.39322 | n/a | n/a | n/a | https://www.digikey.com/en/products/detail/on-shore-technology-inc/302-S161/2794234
AWG28-16/G/300 | 12/300 | 134.63 | 86.5018 | 3.460072 | n/a | n/a | n/a | https://www.digikey.com/en/products/detail/assmann-wsw-components/AWG28-16-G-300/655756
Front Panel PCB | 1/1000 | 7.3 | 389.3 | 3.893 | n/a | n/a | n/a
Main PCB | 1/1000 | 39.9 | 1447.6 | 1.4476 | n/a | n/a | n/a
Front Panel Laminate | 1 | 2 | 2 | 2 | n/a | n/a | n/a
Front Panel Switch | 1 | 1.94 | 1.27 | 1.27 | n/a | n/a | n/a | https://www.mouser.com/ProductDetail/Carling-Technologies/LRA211-RS-B-125N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
AC Power Plug | 1? | 1.49 | 1.15 | 1.15 | n/a | n/a | n/a | https://www.jameco.com/z/JR-101-F-Jameco-Valuepro-Receptacle-Male-10A-250VoltFused-Fast-On-UL-CSA-Vde_265528.html

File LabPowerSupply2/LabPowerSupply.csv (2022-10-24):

Id | Designator | Package | Quantity | Designation | Supplier and ref
1 | C2_SVR1,C2_SVR2 | C_Radial_D8.0mm_H7.0mm_P3.50mm | 2 | 100u
2 | F_CS1,F_CS2 | Fuse_1812_4532Metric | 2 | 290m
3 | C5_Power2,C6_Power1,C7_Power1,C8_Power2,C7_Power2,C10_Power1,C8_Power1,C_CUR1,C6_Power2,C9_Power1,C_CUR2,C2_5V1,C_OPT2,C2_5V2,C_OPT1,C_INV2,C_INV1 | C_0603_1608Metric | 17 | 100n
4 | J_Boot1,ADC342_1,J_Boot2,ADC342_2 | PinHeader_1x03_P2.54mm_Vertical | 4 | Conn_01x03_Male
5 | Linear1_1,Linear1_2 | DFN-8-1EP_3x3mm_P0.5mm_EP1.66x2.38mm | 2 | LT3080xDD
6 | D_SVR1,D2_CP2,D1_CP2,D_LVR2,D_LVR1,D1_CP1,D2_CP1,D_SVR2,D_CS1,D_CS2 | D_SMA | 10 | 1N4001
7 | Output1,Input1,Input2,Output2 | TerminalBlock_Altech_AK300-3_P5.00mm | 4 | Screw_Terminal_01x03
8 | C3_CP2,C1_CP1,C4_CP1,C4_CP2,C2_CP1,C3_CP1,C1_CP2,C2_CP2,C3_5V2,C1_3V1,C3_5V1,C1_3V2 | C_1210_3225Metric | 12 | 22u
9 | D1_2,D2_2,D2_1,A1_1,D1_1,A1_2 | PinHeader_1x01_P2.54mm_Vertical | 6 | Conn_01x01_Male
10 | C1_BR2,C1_BR1,C2_BR2,C2_BR1 | CP_Radial_D18.0mm_P7.50mm | 4 | 6.8m
11 | C3_LVR2,C3_LVR1,C1_SVR1,C1_SVR2,C1_5V1,C1_5V2 | C_1206_3216Metric | 6 | 10u
12 | C3_SVR1,C3_SVR2 | C_0603_1608Metric | 2 | 22n
13 | Q1_LVR1,Q2_LVR1,Q3_LVR1,Q3_LVR2,Q2_LVR2,Q1_LVR2 | SOT95P240X110-3N | 6 | PJA3404_R1_00001
14 | R_I2C1,R_I2C2 | R_0603_1608Metric | 2 | 4.7k
15 | C1_LVR2,C1_LVR1 | C_0805_2012Metric | 2 | 4.7u
16 | C4_LVR1,C4_LVR2,C1_Y2,C2_Y2,C2_Y1,C1_Y1 | C_0603_1608Metric | 6 | 20p
17 | R5_SVR1,R5_SVR2,R2_Boot2,R2_Boot1,R_CC2,R1_Boot1,R1_Boot2,R_CC1 | R_0603_1608Metric | 8 | 5.1k
18 | Q1_CP1,Q1_CP2 | SOT-23 | 2 | FMMT495TA
19 | Switching1,Switching2 | SO-8_3.9x4.9mm_P1.27mm | 2 | L6902D
20 | C5_CP2,C5_CP1 | CP_Radial_D10.0mm_P5.00mm | 2 | 1m
21 | C5_Power1,C2_Power1,C3_Power2,C1_Power1,C4_Power2,C3_Power1,C4_Power1,C2_Power2,C1_Power2,C5_SVR1,C5_SVR2 | C_0603_1608Metric | 11 | 1u
22 | R_CP1,R_CP2,R_Reset1,R_Reset2,R4_LVR2,R2_LVR2,R22_CS2,R4_LVR1,R22_CS1,R10_OA2,R7_OA2,R6_SVR1,R2_OA1,R6_OA1,R6_OA2,R3_LVR2,R3_CS2,R2_LVR1,R4_OA2,R4_OA1,R8_OA2,R7_OA1,R10_OA1,R92_OA2,R3_CS1,R8_OA1,R92_OA1,R2_OA2,R3_OA1,R3_LVR1,R3_OA2,R6_SVR2 | R_0603_1608Metric | 32 | 1k
23 | R1_SVR1,R1_SVR2 | R_0603_1608Metric | 2 | 180m
24 | R12_LVR1,R11_LVR1,R11_LVR2,R12_LVR2,R31_SVR1,R91_OA2,R12_OA2,R32_SVR1,R52_OA1,R21_CS1,R91_OA1,R51_OA1,R32_SVR2,R12_OA1,R52_OA2,R31_SVR2,R21_CS2,R13_OA2,R13_OA1,R51_OA2 | R_0603_1608Metric | 20 | 2k
25 | SW_Reset1,SW_Reset2 | SW_PUSH-12mm | 2 | SW_MEC_5G
26 | C4_SVR2,C4_SVR1 | C_0603_1608Metric | 2 | 220p
27 | Linear2,Linear1 | TO170P457X1022X2306-5P | 2 | LT3083ET#PBF
28 | CurrentSense2,CurrentSense1 | SOT-23-5 | 2 | INA180A1
29 | R1_CS1,R1_CS2 | R_1206_3216Metric | 2 | 300m
30 | L_SVR1,L_SVR2 | L_Sumida_CR75 | 2 | 22u
31 | J_STLink1,J_STLink2 | PinHeader_1x06_P2.54mm_Vertical | 2 | Conn_01x06_Male
32 | Front_Panel1 | IDC-Header_2x08_P2.54mm_Vertical | 1 | Conn_02x08_Counter_Clockwise
33 | J_I2C1 | PinHeader_1x04_P2.54mm_Vertical | 1 | Conn_01x04_Male
34 | R_USB2,R_USB1 | R_0603_1608Metric | 2 | 22
35 | R13_LVR1,R2_SVR1,R13_LVR2,R11_OA2,R_OPT5,R2_SVR2,R11_OA1,R_OPT4,R_OPT6,R_OPT3 | R_0603_1608Metric | 10 | 10k
36 | D2_BR1,D1_BR1,D4_BR1,D3_BR1,D2_BR2,D4_BR2,D1_BR2,D3_BR2 | D_SOD-128 | 8 | PMEG4050EP
37 | R7_SVR2,R41_SVR2,R7_SVR1,R41_SVR1,R42_SVR2,R42_SVR1 | R_0603_1608Metric | 6 | 1.2k
38 | MCU_1 | LQFP-64_10x10mm_P0.5mm | 1 | STM32L151R6TxA
39 | Inverter2,Inverter1 | SSOP-14_5.3x6.2mm_P0.65mm | 2 | 74AHC04
40 | Optocoupler1,Optocoupler2 | PowerIntegrations_SMD-8 | 2 | 6N137
41 | R_OPT2,R_OPT1 | R_0603_1608Metric | 2 | 470
42 | U_3V1,U_3V2 | TO-252-2 | 2 | LP2950-3.3_TO252
43 | L_5V1,L_5V2 | L_Sumida_CDMC6D28_7.25x6.5mm | 2 | 4.7u
44 | C2_3V2,C2_3V1 | C_0805_2012Metric | 2 | 2.2u
45 | OpAmp1,OpAmp2 | SOIC-14_3.9x8.7mm_P1.27mm | 2 | LM324
46 | Y2,Y1 | Crystal_SMD_HC49-SD | 2 | 8M
47 | MCU_2 | QFN-48-1EP_7x7mm_P0.5mm_EP5.6x5.6mm | 1 | STM32L100C6UxA
48 | U_5V2,U_5V1 | TSOT-23-6 | 2 | AP63205WU
49 | J_USB1 | USB_C_Receptacle_Palconn_UTC16-G | 1 | USB_C_Receptacle_USB2.0

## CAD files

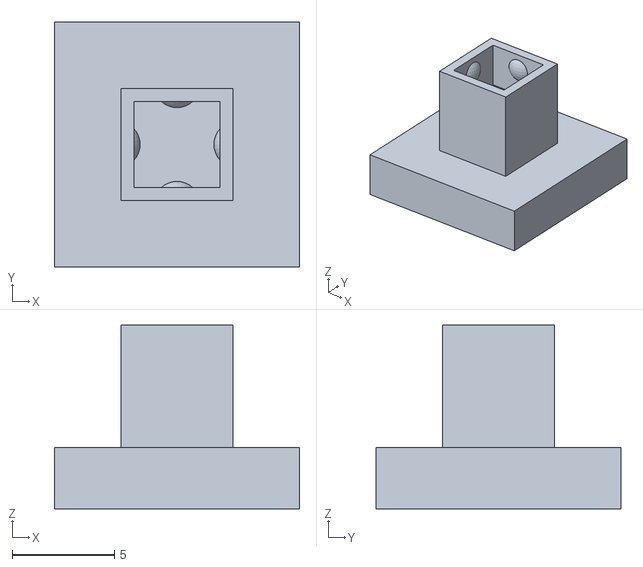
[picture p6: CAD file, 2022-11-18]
3D_Printing/button_caps/button_cap-6.stl
12.0 x 12.0 x 9.00

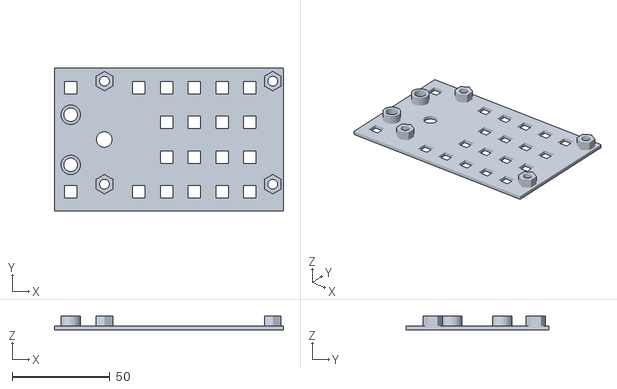
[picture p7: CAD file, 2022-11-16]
3D_Printing/FrontPanelSpacerPlate.stl
117.3 x 73.0 x 7.00

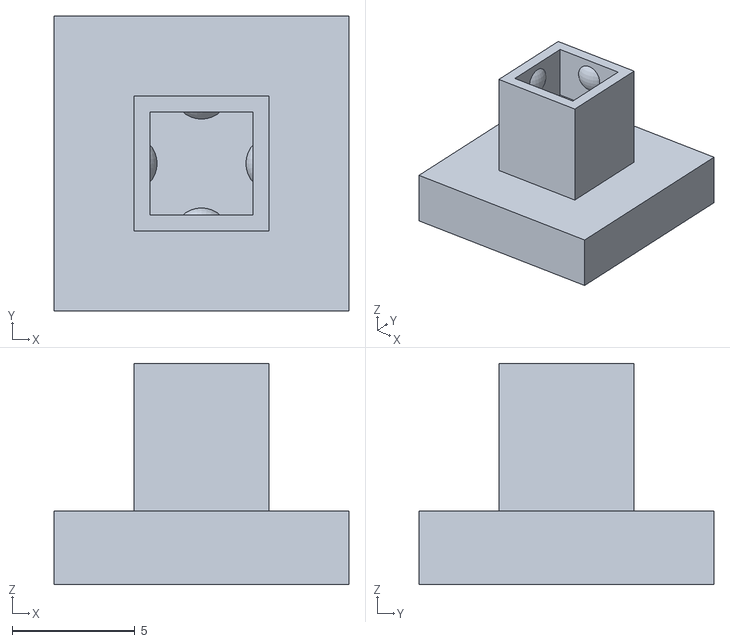
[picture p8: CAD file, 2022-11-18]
3D_Printing/button_caps/button_cap-arrow.stl
12.0 x 12.0 x 9.00

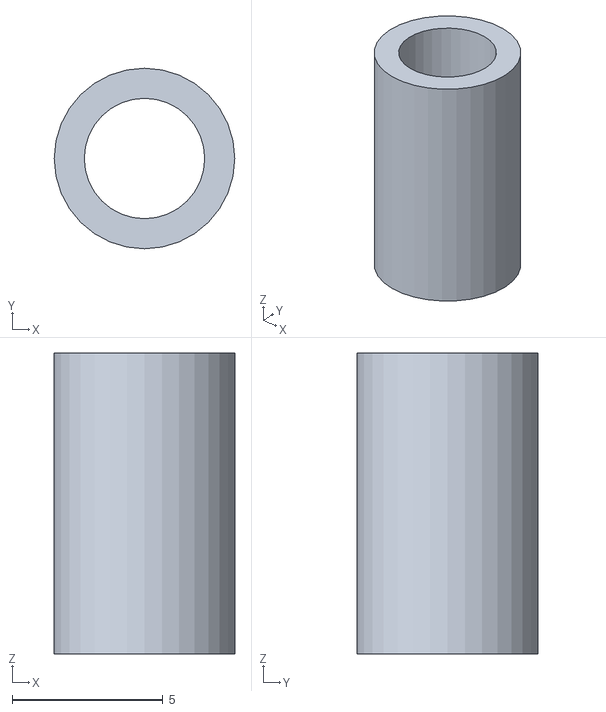
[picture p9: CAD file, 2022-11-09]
3D_Printing/spacer.stl
6.00 x 6.00 x 10.0

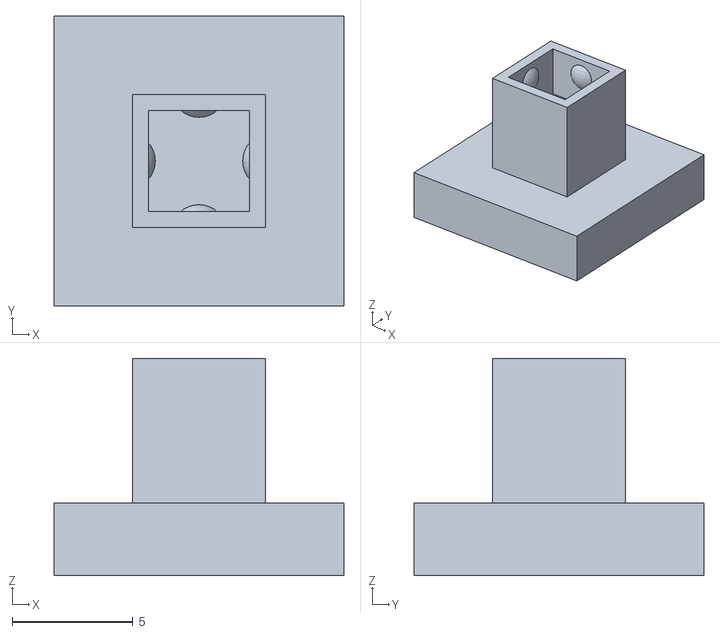
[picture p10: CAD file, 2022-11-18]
3D_Printing/button_caps/button_cap-dot.stl
12.0 x 12.0 x 9.00

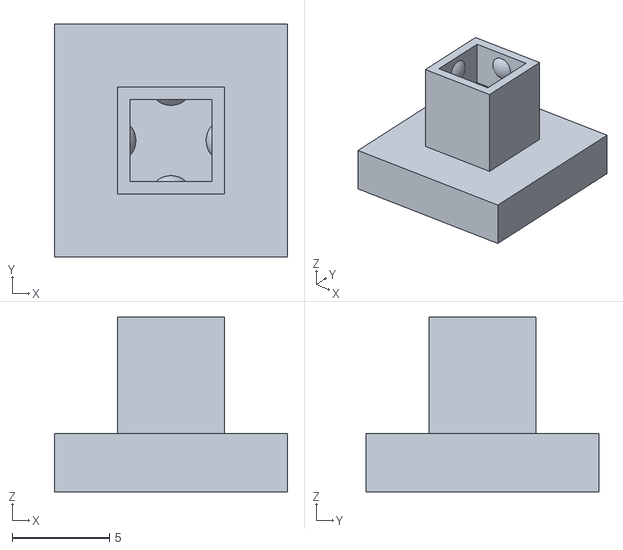
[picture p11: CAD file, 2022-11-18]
3D_Printing/button_caps/button_cap-7.stl
12.0 x 12.0 x 9.00

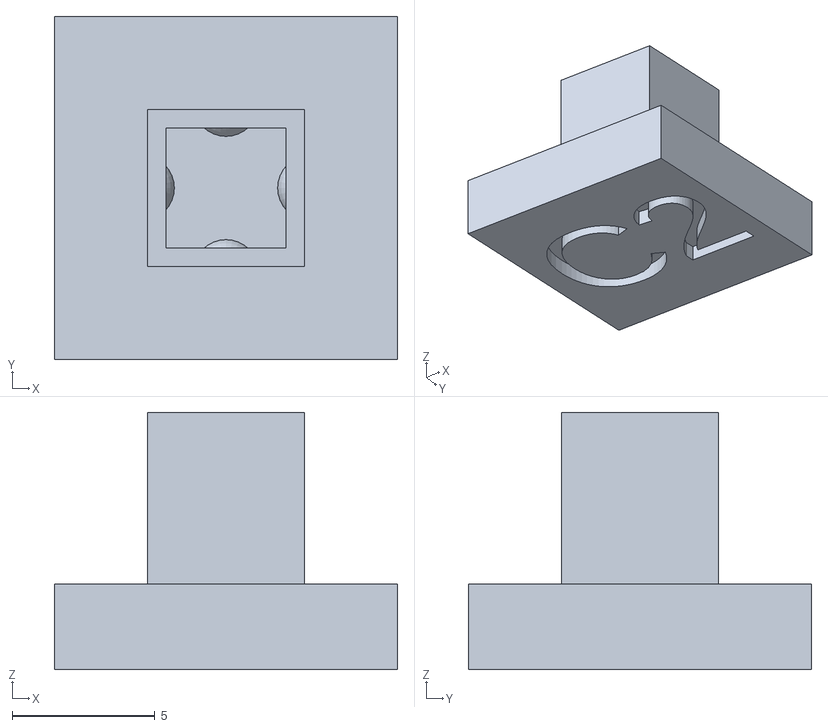
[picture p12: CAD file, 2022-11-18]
3D_Printing/button_caps/button_cap-C2.stl
12.0 x 12.0 x 9.00

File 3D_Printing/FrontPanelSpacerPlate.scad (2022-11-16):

$fn = 32;

module hexagon(point_to_point=4) {
    rotate(30, [0, 0, 1])
        circle(point_to_point, $fn=6);
}

module Post(Width=5) {
    difference() {
        hexagon(Width);
        circle(2.5); // 5mm diamter
    }
}

module front_panel_plate() {
    union() {

        PlateThickness = 2;
        
        AltCols = [8.3, 43.2];
        LEDRows = [23.5, 49.2];
        MountingCols = [25.6, 111.8];
        MountingRows = [13.6, 66.4];

        difference() {
            PostHeight = 5;
            linear_extrude(PostHeight)
                union() {
                    // Mounting Posts
                    for (MountingCol = MountingCols) {
                        for (MountingRow = MountingRows) {
                            translate([MountingCol, MountingRow])
                                Post();
                        }
                    }
                    
                    // LED Posts
                    for (LEDRow = LEDRows) {
                        translate([AltCols[0], LEDRow])
                            difference() {
                                circle(5); // 10mm diameter
                                circle(3.5); // 7mm diameter
                            }
                    }
                }
                
                
            // Cut Out in the Mounting Posts for the Standoffs
            StandoffDepth = 4.2;
            linear_extrude(StandoffDepth)
                union() {
                    for (MountingCol = MountingCols) {
                        for (MountingRow = MountingRows) {
                            translate([MountingCol, MountingRow])
                                Post(4);
                        }
                    }
                }
        }
        
        translate([0, 0, -PlateThickness])
            linear_extrude(PlateThickness)
                difference() {

                    // Main Plate
                    TotalWidth = 73;
                    TotalLength = 117.3;
                    square([TotalLength, TotalWidth]);
                    
                    union() {

                        // Mounting Holes
                        for (MountingCol = MountingCols) {
                            for (MountingRow = MountingRows) {
                                translate([MountingCol, MountingRow])
                                    hexagon();
                            }
                        }

                        // Rotary Encoder Cut-Out
                        translate([25.5, 36.5])
                            circle(4); // 8mm  Diameter
                        
                        // Main Keypad Matrix
                        ButtonHole = 6.4;
                        rows = [63.1, 45.3, 27.5, 9.8];
                        cols = [57.4, 71.6, 85.9, 100.1];
                        for (row = rows) {
                            for (col = cols) {
                                translate([col, row])
                                    square(ButtonHole, center=true);
                            }
                        }

                        // Secondary Buttons
                        
                        for (AltCol = AltCols) {
                            translate([AltCol, rows[0]])
                                square(ButtonHole, center=true);
                            translate([AltCol, rows[3]])
                                square(ButtonHole, center=true);
                        }

                        
                        // LED Cut-Outs
                        LEDHole = 3.5;
                        for (LEDRow = LEDRows) {
                            translate([AltCols[0], LEDRow])
                                circle(LEDHole);
                        }
                    }
                }
    }
}

front_panel_plate();

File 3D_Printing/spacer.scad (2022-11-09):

$fn=32;

module spacer(height = 10, inner_radius = 2, thickness = 1) {
    outer_radius = thickness + inner_radius;
    difference() {
        cylinder(h=height, r=outer_radius);
        cylinder(h=height, r=inner_radius);
    }
}

spacer();

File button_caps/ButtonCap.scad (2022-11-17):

$fn = 32;

Label = "V2";
TextSize = 6;

module Clip(StemOuter, StemInter, ClipHeight) {
    union() {
        difference() {
            linear_extrude(ClipHeight)
                square(StemOuter, center=true);
            linear_extrude(ClipHeight)
                square(StemInter, center=true);
        }
        
        intersection() {
            union() {
                ClipDepth = 0.3;
                IndentHeight = 1;
                BallRadius = (IndentHeight ^ 2) + (ClipDepth / 2);
                BallOffset = (StemInter / 2) + (BallRadius - ClipDepth);
                BallHeight = ClipHeight - BallRadius;
                translate([BallOffset, 0, BallHeight])
                    sphere(BallRadius);
                translate([0, BallOffset, BallHeight])
                    sphere(BallRadius);
                translate([-BallOffset, 0, BallHeight])
                    sphere(BallRadius);
                translate([0, -BallOffset, BallHeight])
                    sphere(BallRadius);
            }
            
            linear_extrude(ClipHeight)
                square(StemInter, center=true);
        }
    }
}

module ButtonBase(ButtonWidth, ButtonThickness, StemLength) {
    union() {
        translate([0, 0, -ButtonThickness])
            linear_extrude(ButtonThickness)
                square(ButtonWidth, center=true);

        StemOuter = 5.5;
        StemInter = 4.2;
        ClipHeight = 3;
        linear_extrude(StemLength - ClipHeight)
            square(StemOuter, center=true);
        translate([0, 0, StemLength - ClipHeight])
            Clip(StemOuter, StemInter, ClipHeight);
    }
}

module Button(Label, TextSize) {
    ButtonWidth = 12;
    ButtonThickness = 3;
    StemLength = 5;

    difference() {
        ButtonBase(ButtonWidth, ButtonThickness, StemLength);

        translate([0, 0, -ButtonThickness])
            linear_extrude(ButtonThickness/4)
                mirror([0, 1, 0])
                    text(Label, size=TextSize, halign="center", valign="center", font="Liberation Sans; style=bold");
    }
}
Button(Label, TextSize);

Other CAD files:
3D_Printing/button_caps/button_cap-3.stl
3D_Printing/button_caps/button_cap-V2.stl
3D_Printing/button_caps/button_cap-A1.stl
3D_Printing/button_caps/button_cap-4.stl
3D_Printing/button_caps/button_cap-5.stl
3D_Printing/button_caps/button_cap-2.stl
3D_Printing/button_caps/button_cap-A2.stl
3D_Printing/button_caps/button_cap-cross.stl
3D_Printing/button_caps/button_cap-8.stl
3D_Printing/button_caps/button_cap-C1.stl
3D_Printing/button_caps/button_cap-check.stl
MyButtons/ButtonCap.scad
3D_Printing/button_caps/ButtonCap.scad
3D_Printing/button_caps/button_cap-0.stl
3D_Printing/button_caps/button_cap-1.stl
3D_Printing/button_caps/button_cap-V1.stl

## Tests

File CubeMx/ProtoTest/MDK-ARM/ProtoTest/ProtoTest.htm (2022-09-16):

# Static Call Graph for image ProtoTest\ProtoTest.axf

#<CALLGRAPH># ARM Linker, 5060960: Last Updated: Thu Sep 15 13:51:16 2022

### Maximum Stack Usage = 324 bytes + Unknown(Functions without stacksize, Cycles, Untraceable Function Pointers)

### Call chain for Maximum Stack Depth:

_printf_f ⇒ _printf_fp_dec ⇒ _printf_fp_dec_real ⇒ _fp_digits ⇒ _btod_etento ⇒ _btod_emul ⇒ _e2e

### Functions with no stack information

- __user_initial_stackheap

### Mutually Recursive functions

- ADC1_IRQHandler ⇒ ADC1_IRQHandler
- BusFault_Handler ⇒ BusFault_Handler
- HardFault_Handler ⇒ HardFault_Handler
- MemManage_Handler ⇒ MemManage_Handler
- NMI_Handler ⇒ NMI_Handler
- UsageFault_Handler ⇒ UsageFault_Handler

### Function Pointers

- ADC1_IRQHandler from startup_stm32l151xba.o(.text) referenced from startup_stm32l151xba.o(RESET)
- ADC_DMAConvCplt from stm32l1xx_hal_adc.o(i.ADC_DMAConvCplt) referenced from stm32l1xx_hal_adc.o(i.HAL_ADC_Start_DMA)
- ADC_DMAError from stm32l1xx_hal_adc.o(i.ADC_DMAError) referenced from stm32l1xx_hal_adc.o(i.HAL_ADC_Start_DMA)
- ADC_DMAHalfConvCplt from stm32l1xx_hal_adc.o(i.ADC_DMAHalfConvCplt) referenced from stm32l1xx_hal_adc.o(i.HAL_ADC_Start_DMA)
- BusFault_Handler from stm32l1xx_it.o(i.BusFault_Handler) referenced from startup_stm32l151xba.o(RESET)
- CDC_Control_FS from usbd_cdc_if.o(i.CDC_Control_FS) referenced 2 times from usbd_cdc_if.o(.data)
- CDC_DeInit_FS from usbd_cdc_if.o(i.CDC_DeInit_FS) referenced 2 times from usbd_cdc_if.o(.data)
- CDC_Init_FS from usbd_cdc_if.o(i.CDC_Init_FS) referenced 2 times from usbd_cdc_if.o(.data)
- CDC_Receive_FS from usbd_cdc_if.o(i.CDC_Receive_FS) referenced 2 times from usbd_cdc_if.o(.data)
- COMP_IRQHandler from startup_stm32l151xba.o(.text) referenced from startup_stm32l151xba.o(RESET)
- DAC_IRQHandler from startup_stm32l151xba.o(.text) referenced from startup_stm32l151xba.o(RESET)
- DMA1_Channel1_IRQHandler from stm32l1xx_it.o(i.DMA1_Channel1_IRQHandler) referenced from startup_stm32l151xba.o(RESET)
- DMA1_Channel2_IRQHandler from startup_stm32l151xba.o(.text) referenced from startup_stm32l151xba.o(RESET)
- DMA1_Channel3_IRQHandler from startup_stm32l151xba.o(.text) referenced from startup_stm32l151xba.o(RESET)
- DMA1_Channel4_IRQHandler from startup_stm32l151xba.o(.text) referenced from startup_stm32l151xba.o(RESET)
- DMA1_Channel5_IRQHandler from startup_stm32l151xba.o(.text) referenced from startup_stm32l151xba.o(RESET)
- DMA1_Channel6_IRQHandler from startup_stm32l151xba.o(.text) referenced from startup_stm32l151xba.o(RESET)
- DMA1_Channel7_IRQHandler from startup_stm32l151xba.o(.text) referenced from startup_stm32l151xba.o(RESET)
- DebugMon_Handler from stm32l1xx_it.o(i.DebugMon_Handler) referenced from startup_stm32l151xba.o(RESET)
- EXTI0_IRQHandler from stm32l1xx_it.o(i.EXTI0_IRQHandler) referenced from startup_stm32l151xba.o(RESET)
- EXTI15_10_IRQHandler from stm32l1xx_it.o(i.EXTI15_10_IRQHandler) referenced from startup_stm32l151xba.o(RESET)
- EXTI1_IRQHandler from main.o(i.EXTI1_IRQHandler) referenced from startup_stm32l151xba.o(RESET)
- EXTI2_IRQHandler from startup_stm32l151xba.o(.text) referenced from startup_stm32l151xba.o(RESET)
- EXTI3_IRQHandler from startup_stm32l151xba.o(.text) referenced from startup_stm32l151xba.o(RESET)
- EXTI4_IRQHandler from startup_stm32l151xba.o(.text) referenced from startup_stm32l151xba.o(RESET)
- EXTI9_5_IRQHandler from startup_stm32l151xba.o(.text) referenced from startup_stm32l151xba.o(RESET)
- FLASH_IRQHandler from startup_stm32l151xba.o(.text) referenced from startup_stm32l151xba.o(RESET)
- HardFault_Handler from stm32l1xx_it.o(i.HardFault_Handler) referenced from startup_stm32l151xba.o(RESET)
- I2C1_ER_IRQHandler from startup_stm32l151xba.o(.text) referenced from startup_stm32l151xba.o(RESET)
- I2C1_EV_IRQHandler from startup_stm32l151xba.o(.text) referenced from startup_stm32l151xba.o(RESET)
- I2C2_ER_IRQHandler from startup_stm32l151xba.o(.text) referenced from startup_stm32l151xba.o(RESET)
- I2C2_EV_IRQHandler from startup_stm32l151xba.o(.text) referenced from startup_stm32l151xba.o(RESET)
- MemManage_Handler from stm32l1xx_it.o(i.MemManage_Handler) referenced from startup_stm32l151xba.o(RESET)
- NMI_Handler from stm32l1xx_it.o(i.NMI_Handler) referenced from startup_stm32l151xba.o(RESET)
- PVD_IRQHandler from startup_stm32l151xba.o(.text) referenced from startup_stm32l151xba.o(RESET)
- PendSV_Handler from stm32l1xx_it.o(i.PendSV_Handler) referenced from startup_stm32l151xba.o(RESET)
- RCC_IRQHandler from startup_stm32l151xba.o(.text) referenced from startup_stm32l151xba.o(RESET)
- RTC_Alarm_IRQHandler from startup_stm32l151xba.o(.text) referenced from startup_stm32l151xba.o(RESET)
- RTC_WKUP_IRQHandler from startup_stm32l151xba.o(.text) referenced from startup_stm32l151xba.o(RESET)
- Reset_Handler from startup_stm32l151xba.o(.text) referenced from startup_stm32l151xba.o(RESET)
- SPI1_IRQHandler from startup_stm32l151xba.o(.text) referenced from startup_stm32l151xba.o(RESET)
- SPI2_IRQHandler from startup_stm32l151xba.o(.text) referenced from startup_stm32l151xba.o(RESET)
- SVC_Handler from stm32l1xx_it.o(i.SVC_Handler) referenced from startup_stm32l151xba.o(RESET)
- SysTick_Handler from stm32l1xx_it.o(i.SysTick_Handler) referenced from startup_stm32l151xba.o(RESET)
- SystemInit from system_stm32l1xx.o(i.SystemInit) referenced from startup_stm32l151xba.o(.text)
- TAMPER_STAMP_IRQHandler from startup_stm32l151xba.o(.text) referenced from startup_stm32l151xba.o(RESET)
- TIM10_IRQHandler from startup_stm32l151xba.o(.text) referenced from startup_stm32l151xba.o(RESET)
- TIM11_IRQHandler from startup_stm32l151xba.o(.text) referenced from startup_stm32l151xba.o(RESET)
- TIM2_IRQHandler from stm32l1xx_it.o(i.TIM2_IRQHandler) referenced from startup_stm32l151xba.o(RESET)
- TIM3_IRQHandler from stm32l1xx_it.o(i.TIM3_IRQHandler) referenced from startup_stm32l151xba.o(RESET)
- TIM4_IRQHandler from startup_stm32l151xba.o(.text) referenced from startup_stm32l151xba.o(RESET)
- TIM6_IRQHandler from startup_stm32l151xba.o(.text) referenced from startup_stm32l151xba.o(RESET)
- TIM7_IRQHandler from startup_stm32l151xba.o(.text) referenced from startup_stm32l151xba.o(RESET)
- TIM9_IRQHandler from startup_stm32l151xba.o(.text) referenced from startup_stm32l151xba.o(RESET)
- USART1_IRQHandler from startup_stm32l151xba.o(.text) referenced from startup_stm32l151xba.o(RESET)
- USART2_IRQHandler from startup_stm32l151xba.o(.text) referenced from startup_stm32l151xba.o(RESET)
- USART3_IRQHandler from startup_stm32l151xba.o(.text) referenced from startup_stm32l151xba.o(RESET)
- USBD_CDC_DataIn from usbd_cdc.o(i.USBD_CDC_DataIn) referenced 2 times from usbd_cdc.o(.data)
- USBD_CDC_DataOut from usbd_cdc.o(i.USBD_CDC_DataOut) referenced 2 times from usbd_cdc.o(.data)
- USBD_CDC_DeInit from usbd_cdc.o(i.USBD_CDC_DeInit) referenced 2 times from usbd_cdc.o(.data)
- USBD_CDC_EP0_RxReady from usbd_cdc.o(i.USBD_CDC_EP0_RxReady) referenced 2 times from usbd_cdc.o(.data)
- USBD_CDC_GetDeviceQualifierDescriptor from usbd_cdc.o(i.USBD_CDC_GetDeviceQualifierDescriptor) referenced 2 times from usbd_cdc.o(.data)
- USBD_CDC_GetFSCfgDesc from usbd_cdc.o(i.USBD_CDC_GetFSCfgDesc) referenced 2 times from usbd_cdc.o(.data)
- USBD_CDC_GetHSCfgDesc from usbd_cdc.o(i.USBD_CDC_GetHSCfgDesc) referenced 2 times from usbd_cdc.o(.data)
- USBD_CDC_GetOtherSpeedCfgDesc from usbd_cdc.o(i.USBD_CDC_GetOtherSpeedCfgDesc) referenced 2 times from usbd_cdc.o(.data)
- USBD_CDC_Init from usbd_cdc.o(i.USBD_CDC_Init) referenced 2 times from usbd_cdc.o(.data)
- USBD_CDC_Setup from usbd_cdc.o(i.USBD_CDC_Setup) referenced 2 times from usbd_cdc.o(.data)
- USBD_FS_ConfigStrDescriptor from usbd_desc.o(i.USBD_FS_ConfigStrDescriptor) referenced 2 times from usbd_desc.o(.data)
- USBD_FS_DeviceDescriptor from usbd_desc.o(i.USBD_FS_DeviceDescriptor) referenced 2 times from usbd_desc.o(.data)
- USBD_FS_InterfaceStrDescriptor from usbd_desc.o(i.USBD_FS_InterfaceStrDescriptor) referenced 2 times from usbd_desc.o(.data)
- USBD_FS_LangIDStrDescriptor from usbd_desc.o(i.USBD_FS_LangIDStrDescriptor) referenced 2 times from usbd_desc.o(.data)
- USBD_FS_ManufacturerStrDescriptor from usbd_desc.o(i.USBD_FS_ManufacturerStrDescriptor) referenced 2 times from usbd_desc.o(.data)
- USBD_FS_ProductStrDescriptor from usbd_desc.o(i.USBD_FS_ProductStrDescriptor) referenced 2 times from usbd_desc.o(.data)
- USBD_FS_SerialStrDescriptor from usbd_desc.o(i.USBD_FS_SerialStrDescriptor) referenced 2 times from usbd_desc.o(.data)
- USB_FS_WKUP_IRQHandler from startup_stm32l151xba.o(.text) referenced from startup_stm32l151xba.o(RESET)
- USB_HP_IRQHandler from startup_stm32l151xba.o(.text) referenced from startup_stm32l151xba.o(RESET)
- USB_LP_IRQHandler from stm32l1xx_it.o(i.USB_LP_IRQHandler) referenced from startup_stm32l151xba.o(RESET)
- UsageFault_Handler from stm32l1xx_it.o(i.UsageFault_Handler) referenced from startup_stm32l151xba.o(RESET)
- WWDG_IRQHandler from startup_stm32l151xba.o(.text) referenced from startup_stm32l151xba.o(RESET)
- __main from __main.o(!!!main) referenced from startup_stm32l151xba.o(.text)
- _printf_input_char from _printf_char_common.o(.text) referenced from _printf_char_common.o(.text)
- _snputc from _snputc.o(.text) referenced from noretval__2snprintf.o(.text)

### Global Symbols

__main (Thumb, 8 bytes, Stack size 0 bytes, __main.o(!!!main))

[Calls]

- >> __scatterload
- >> __rt_entry

__scatterload (Thumb, 0 bytes, Stack size unknown bytes, __scatter.o(!!!scatter))

[Called By]

- >> __main

__scatterload_rt2 (Thumb, 44 bytes, Stack size unknown bytes, __scatter.o(!!!scatter), UNUSED)

[Calls]

- >> __rt_entry

__scatterload_rt2_thumb_only (Thumb, 0 bytes, Stack size unknown bytes, __scatter.o(!!!scatter), UNUSED)

__scatterload_null (Thumb, 0 bytes, Stack size unknown bytes, __scatter.o(!!!scatter), UNUSED)

__decompress (Thumb, 90 bytes, Stack size unknown bytes, __dczerorl2.o(!!dczerorl2), UNUSED)

__decompress1 (Thumb, 0 bytes, Stack size unknown bytes, __dczerorl2.o(!!dczerorl2), UNUSED)

__scatterload_zeroinit (Thumb, 28 bytes, Stack size unknown bytes, __scatter_zi.o(!!handler_zi), UNUSED)

_printf_f (Thumb, 0 bytes, Stack size unknown bytes, _printf_f.o(.ARM.Collect$$_printf_percent$$00000003))

[Stack]

- Max Depth = 324 + Unknown Stack Size
- Call Chain = _printf_f ⇒ _printf_fp_dec ⇒ _printf_fp_dec_real ⇒ _fp_digits ⇒ _btod_etento ⇒ _btod_emul ⇒ _e2e

[Calls]

- >> _printf_fp_dec

_printf_percent (Thumb, 0 bytes, Stack size unknown bytes, _printf_percent.o(.ARM.Collect$$_printf_percent$$00000000))

[Called By]

- >> __printf

_printf_percent_end (Thumb, 0 bytes, Stack size unknown bytes, _printf_percent_end.o(.ARM.Collect$$_printf_percent$$00000017))

__rt_lib_init (Thumb, 0 bytes, Stack size unknown bytes, libinit.o(.ARM.Collect$$libinit$$00000000))

[Called By]

- >> __rt_entry_li

__rt_lib_init_fp_1 (Thumb, 0 bytes, Stack size unknown bytes, libinit2.o(.ARM.Collect$$libinit$$00000002))

__rt_lib_init_heap_1 (Thumb, 0 bytes, Stack size unknown bytes, libinit2.o(.ARM.Collect$$libinit$$0000000A))

__rt_lib_init_lc_common (Thumb, 0 bytes, Stack size unknown bytes, libinit2.o(.ARM.Collect$$libinit$$0000000F))

[Calls]

- >> __rt_locale

__rt_lib_init_preinit_1 (Thumb, 0 bytes, Stack size unknown bytes, libinit2.o(.ARM.Collect$$libinit$$00000004))

__rt_lib_init_rand_1 (Thumb, 0 bytes, Stack size unknown bytes, libinit2.o(.ARM.Collect$$libinit$$0000000E))

__rt_lib_init_user_alloc_1 (Thumb, 0 bytes, Stack size unknown bytes, libinit2.o(.ARM.Collect$$libinit$$0000000C))

__rt_lib_init_lc_collate_1 (Thumb, 0 bytes, Stack size unknown bytes, libinit2.o(.ARM.Collect$$libinit$$00000011))

__rt_lib_init_lc_ctype_1 (Thumb, 0 bytes, Stack size unknown bytes, libinit2.o(.ARM.Collect$$libinit$$00000013))

__rt_lib_init_lc_monetary_1 (Thumb, 0 bytes, Stack size unknown bytes, libinit2.o(.ARM.Collect$$libinit$$00000015))

__rt_lib_init_lc_numeric_2 (Thumb, 0 bytes, Stack size unknown bytes, libinit2.o(.ARM.Collect$$libinit$$00000016))

[Stack]

- Max Depth = 8 + Unknown Stack Size
- Call Chain = __rt_lib_init_lc_numeric_2 ⇒ _get_lc_numeric

[Calls]

- >> _get_lc_numeric

__rt_lib_init_alloca_1 (Thumb, 0 bytes, Stack size unknown bytes, libinit2.o(.ARM.Collect$$libinit$$0000002E))

__rt_lib_init_argv_1 (Thumb, 0 bytes, Stack size unknown bytes, libinit2.o(.ARM.Collect$$libinit$$0000002C))

__rt_lib_init_atexit_1 (Thumb, 0 bytes, Stack size unknown bytes, libinit2.o(.ARM.Collect$$libinit$$0000001B))

__rt_lib_init_clock_1 (Thumb, 0 bytes, Stack size unknown bytes, libinit2.o(.ARM.Collect$$libinit$$00000021))

__rt_lib_init_cpp_1 (Thumb, 0 bytes, Stack size unknown bytes, libinit2.o(.ARM.Collect$$libinit$$00000032))

__rt_lib_init_exceptions_1 (Thumb, 0 bytes, Stack size unknown bytes, libinit2.o(.ARM.Collect$$libinit$$00000030))

__rt_lib_init_fp_trap_1 (Thumb, 0 bytes, Stack size unknown bytes, libinit2.o(.ARM.Collect$$libinit$$0000001F))

__rt_lib_init_getenv_1 (Thumb, 0 bytes, Stack size unknown bytes, libinit2.o(.ARM.Collect$$libinit$$00000023))

__rt_lib_init_lc_numeric_1 (Thumb, 0 bytes, Stack size unknown bytes, libinit2.o(.ARM.Collect$$libinit$$00000017))

__rt_lib_init_lc_time_1 (Thumb, 0 bytes, Stack size unknown bytes, libinit2.o(.ARM.Collect$$libinit$$00000019))

__rt_lib_init_return (Thumb, 0 bytes, Stack size unknown bytes, libinit2.o(.ARM.Collect$$libinit$$00000033))

__rt_lib_init_signal_1 (Thumb, 0 bytes, Stack size unknown bytes, libinit2.o(.ARM.Collect$$libinit$$0000001D))

__rt_lib_init_stdio_1 (Thumb, 0 bytes, Stack size unknown bytes, libinit2.o(.ARM.Collect$$libinit$$00000025))

__rt_lib_shutdown (Thumb, 0 bytes, Stack size unknown bytes, libshutdown.o(.ARM.Collect$$libshutdown$$00000000))

[Called By]

- >> __rt_exit_ls

__rt_lib_shutdown_cpp_1 (Thumb, 0 bytes, Stack size unknown bytes, libshutdown2.o(.ARM.Collect$$libshutdown$$00000004))

__rt_lib_shutdown_fini_1 (Thumb, 0 bytes, Stack size unknown bytes, libshutdown2.o(.ARM.Collect$$libshutdown$$00000002))

__rt_lib_shutdown_fp_trap_1 (Thumb, 0 bytes, Stack size unknown bytes, libshutdown2.o(.ARM.Collect$$libshutdown$$00000009))

__rt_lib_shutdown_heap_1 (Thumb, 0 bytes, Stack size unknown bytes, libshutdown2.o(.ARM.Collect$$libshutdown$$00000011))

__rt_lib_shutdown_return (Thumb, 0 bytes, Stack size unknown bytes, libshutdown2.o(.ARM.Collect$$libshutdown$$00000012))

__rt_lib_shutdown_signal_1 (Thumb, 0 bytes, Stack size unknown bytes, libshutdown2.o(.ARM.Collect$$libshutdown$$0000000C))

__rt_lib_shutdown_stdio_1 (Thumb, 0 bytes, Stack size unknown bytes, libshutdown2.o(.ARM.Collect$$libshutdown$$00000006))

__rt_lib_shutdown_user_alloc_1 (Thumb, 0 bytes, Stack size unknown bytes, libshutdown2.o(.ARM.Collect$$libshutdown$$0000000E))

__rt_entry (Thumb, 0 bytes, Stack size unknown bytes, __rtentry.o(.ARM.Collect$$rtentry$$00000000))

[Called By]

- >> __scatterload_rt2
- >> __main

__rt_entry_presh_1 (Thumb, 0 bytes, Stack size unknown bytes, __rtentry2.o(.ARM.Collect$$rtentry$$00000002))

__rt_entry_sh (Thumb, 0 bytes, Stack size unknown bytes, __rtentry4.o(.ARM.Collect$$rtentry$$00000004))

[Stack]

- Max Depth = 8 + Unknown Stack Size
- Call Chain = __rt_entry_sh ⇒ __user_setup_stackheap

[Calls]

- >> __user_setup_stackheap

__rt_entry_li (Thumb, 0 bytes, Stack size unknown bytes, __rtentry2.o(.ARM.Collect$$rtentry$$0000000A))

[Calls]

- >> __rt_lib_init

__rt_entry_postsh_1 (Thumb, 0 bytes, Stack size unknown bytes, __rtentry2.o(.ARM.Collect$$rtentry$$00000009))

__rt_entry_main (Thumb, 0 bytes, Stack size unknown bytes, __rtentry2.o(.ARM.Collect$$rtentry$$0000000D))

[Stack]

- Max Depth = 192 + Unknown Stack Size
- Call Chain = __rt_entry_main ⇒ main ⇒ SystemClock_Config ⇒ HAL_RCC_ClockConfig ⇒ HAL_RCC_GetSysClockFreq ⇒ __aeabi_uldivmod

[Calls]

- >> main
- >> exit

__rt_entry_postli_1 (Thumb, 0 bytes, Stack size unknown bytes, __rtentry2.o(.ARM.Collect$$rtentry$$0000000C))

__rt_exit (Thumb, 0 bytes, Stack size unknown bytes, rtexit.o(.ARM.Collect$$rtexit$$00000000))

[Called By]

- >> exit

__rt_exit_ls (Thumb, 0 bytes, Stack size unknown bytes, rtexit2.o(.ARM.Collect$$rtexit$$00000003))

[Calls]

- >> __rt_lib_shutdown

__rt_exit_prels_1 (Thumb, 0 bytes, Stack size unknown bytes, rtexit2.o(.ARM.Collect$$rtexit$$00000002))

__rt_exit_exit (Thumb, 0 bytes, Stack size unknown bytes, rtexit2.o(.ARM.Collect$$rtexit$$00000004))

[Calls]

- >> _sys_exit

Reset_Handler (Thumb, 8 bytes, Stack size 0 bytes, startup_stm32l151xba.o(.text))
[Address Reference Count : 1]

- startup_stm32l151xba.o(RESET)

ADC1_IRQHandler (Thumb, 0 bytes, Stack size 0 bytes, startup_stm32l151xba.o(.text))

[Calls]

- >> ADC1_IRQHandler

[Called By]

- >> ADC1_IRQHandler

[Address Reference Count : 1]

- startup_stm32l151xba.o(RESET)

COMP_IRQHandler (Thumb, 0 bytes, Stack size 0 bytes, startup_stm32l151xba.o(.text))
[Address Reference Count : 1]

- startup_stm32l151xba.o(RESET)

DAC_IRQHandler (Thumb, 0 bytes, Stack size 0 bytes, startup_stm32l151xba.o(.text))
[Address Reference Count : 1]

- startup_stm32l151xba.o(RESET)

DMA1_Channel2_IRQHandler (Thumb, 0 bytes, Stack size 0 bytes, startup_stm32l151xba.o(.text))
[Address Reference Count : 1]

- startup_stm32l151xba.o(RESET)

DMA1_Channel3_IRQHandler (Thumb, 0 bytes, Stack size 0 bytes, startup_stm32l151xba.o(.text))
[Address Reference Count : 1]

- startup_stm32l151xba.o(RESET)

DMA1_Channel4_IRQHandler (Thumb, 0 bytes, Stack size 0 bytes, startup_stm32l151xba.o(.text))
[Address Reference Count : 1]

- startup_stm32l151xba.o(RESET)

DMA1_Channel5_IRQHandler (Thumb, 0 bytes, Stack size 0 bytes, startup_stm32l151xba.o(.text))
[Address Reference Count : 1]

- startup_stm32l151xba.o(RESET)

DMA1_Channel6_IRQHandler (Thumb, 0 bytes, Stack size 0 bytes, startup_stm32l151xba.o(.text))
[Address Reference Count : 1]

- startup_stm32l151xba.o(RESET)

DMA1_Channel7_IRQHandler (Thumb, 0 bytes, Stack size 0 bytes, startup_stm32l151xba.o(.text))
[Address Reference Count : 1]

- startup_stm32l151xba.o(RESET)

EXTI2_IRQHandler (Thumb, 0 bytes, Stack size 0 bytes, startup_stm32l151xba.o(.text))
[Address Reference Count : 1]

- startup_stm32l151xba.o(RESET)

EXTI3_IRQHandler (Thumb, 0 bytes, Stack size 0 bytes, startup_stm32l151xba.o(.text))
[Address Reference Count : 1]

- startup_stm32l151xba.o(RESET)

EXTI4_IRQHandler (Thumb, 0 bytes, Stack size 0 bytes, startup_stm32l151xba.o(.text))
[Address Reference Count : 1]

- startup_stm32l151xba.o(RESET)

EXTI9_5_IRQHandler (Thumb, 0 bytes, Stack size 0 bytes, startup_stm32l151xba.o(.text))
[Address Reference Count : 1]

- startup_stm32l151xba.o(RESET)

FLASH_IRQHandler (Thumb, 0 bytes, Stack size 0 bytes, startup_stm32l151xba.o(.text))
[Address Reference Count : 1]

- startup_stm32l151xba.o(RESET)

I2C1_ER_IRQHandler (Thumb, 0 bytes, Stack size 0 bytes, startup_stm32l151xba.o(.text))
[Address Reference Count : 1]

- startup_stm32l151xba.o(RESET)

I2C1_EV_IRQHandler (Thumb, 0 bytes, Stack size 0 bytes, startup_stm32l151xba.o(.text))
[Address Reference Count : 1]

- startup_stm32l151xba.o(RESET)

I2C2_ER_IRQHandler (Thumb, 0 bytes, Stack size 0 bytes, startup_stm32l151xba.o(.text))
[Address Reference Count : 1]

- startup_stm32l151xba.o(RESET)

I2C2_EV_IRQHandler (Thumb, 0 bytes, Stack size 0 bytes, startup_stm32l151xba.o(.text))
[Address Reference Count : 1]

- startup_stm32l151xba.o(RESET)

PVD_IRQHandler (Thumb, 0 bytes, Stack size 0 bytes, startup_stm32l151xba.o(.text))
[Address Reference Count : 1]

- startup_stm32l151xba.o(RESET)

RCC_IRQHandler (Thumb, 0 bytes, Stack size 0 bytes, startup_stm32l151xba.o(.text))
[Address Reference Count : 1]

- startup_stm32l151xba.o(RESET)

RTC_Alarm_IRQHandler (Thumb, 0 bytes, Stack size 0 bytes, startup_stm32l151xba.o(.text))
[Address Reference Count : 1]

- startup_stm32l151xba.o(RESET)

RTC_WKUP_IRQHandler (Thumb, 0 bytes, Stack size 0 bytes, startup_stm32l151xba.o(.text))
[Address Reference Count : 1]

- startup_stm32l151xba.o(RESET)

SPI1_IRQHandler (Thumb, 0 bytes, Stack size 0 bytes, startup_stm32l151xba.o(.text))
[Address Reference Count : 1]

- startup_stm32l151xba.o(RESET)

SPI2_IRQHandler (Thumb, 0 bytes, Stack size 0 bytes, startup_stm32l151xba.o(.text))
[Address Reference Count : 1]

- startup_stm32l151xba.o(RESET)

TAMPER_STAMP_IRQHandler (Thumb, 0 bytes, Stack size 0 bytes, startup_stm32l151xba.o(.text))
[Address Reference Count : 1]

- startup_stm32l151xba.o(RESET)

TIM10_IRQHandler (Thumb, 0 bytes, Stack size 0 bytes, startup_stm32l151xba.o(.text))
[Address Reference Count : 1]

- startup_stm32l151xba.o(RESET)

TIM11_IRQHandler (Thumb, 0 bytes, Stack size 0 bytes, startup_stm32l151xba.o(.text))
[Address Reference Count : 1]

- startup_stm32l151xba.o(RESET)

TIM4_IRQHandler (Thumb, 0 bytes, Stack size 0 bytes, startup_stm32l151xba.o(.text))
[Address Reference Count : 1]

- startup_stm32l151xba.o(RESET)

TIM6_IRQHandler (Thumb, 0 bytes, Stack size 0 bytes, startup_stm32l151xba.o(.text))
[Address Reference Count : 1]

- startup_stm32l151xba.o(RESET)

TIM7_IRQHandler (Thumb, 0 bytes, Stack size 0 bytes, startup_stm32l151xba.o(.text))
[Address Reference Count : 1]

- startup_stm32l151xba.o(RESET)

TIM9_IRQHandler (Thumb, 0 bytes, Stack size 0 bytes, startup_stm32l151xba.o(.text))
[Address Reference Count : 1]

- startup_stm32l151xba.o(RESET)

USART1_IRQHandler (Thumb, 0 bytes, Stack size 0 bytes, startup_stm32l151xba.o(.text))
[Address Reference Count : 1]

- startup_stm32l151xba.o(RESET)

USART2_IRQHandler (Thumb, 0 bytes, Stack size 0 bytes, startup_stm32l151xba.o(.text))
[Address Reference Count : 1]

- startup_stm32l151xba.o(RESET)

USART3_IRQHandler (Thumb, 0 bytes, Stack size 0 bytes, startup_stm32l151xba.o(.text))
[Address Reference Count : 1]

- startup_stm32l151xba.o(RESET)

USB_FS_WKUP_IRQHandler (Thumb, 0 bytes, Stack size 0 bytes, startup_stm32l151xba.o(.text))
[Address Reference Count : 1]

- startup_stm32l151xba.o(RESET)

USB_HP_IRQHandler (Thumb, 0 bytes, Stack size 0 bytes, startup_stm32l151xba.o(.text))
[Address Reference Count : 1]

- startup_stm32l151xba.o(RESET)

WWDG_IRQHandler (Thumb, 0 bytes, Stack size 0 bytes, startup_stm32l151xba.o(.text))
[Address Reference Count : 1]

- startup_stm32l151xba.o(RESET)

__user_initial_stackheap (Thumb, 0 bytes, Stack size unknown bytes, startup_stm32l151xba.o(.text))

[Called By]

- >> __user_setup_stackheap

__aeabi_uldivmod (Thumb, 0 bytes, Stack size 48 bytes, lludivv7m.o(.text))

[Stack]

- Max Depth = 48
- Call Chain = __aeabi_uldivmod

[Called By]

- >> HAL_RCC_GetSysClockFreq

_ll_udiv (Thumb, 238 bytes, Stack size 48 bytes, lludivv7m.o(.text), UNUSED)

__2snprintf (Thumb, 48 bytes, Stack size 32 bytes, noretval__2snprintf.o(.text))

[Stack]

- Max Depth = 128 + Unknown Stack Size
- Call Chain = __2snprintf ⇒ _printf_char_common ⇒ __printf

[Calls]

- >> _sputc
- >> _printf_char_common

[Called By]

- >> lcd_update_voltage
- >> lcd_update_amperage

__printf (Thumb, 270 bytes, Stack size 32 bytes, __printf_wp.o(.text))

[Stack]

- Max Depth = 32 + Unknown Stack Size
- Call Chain = __printf

[Calls]

- >> _printf_percent
- >> _is_digit

[Called By]

- >> _printf_char_common

__aeabi_memcpy (Thumb, 0 bytes, Stack size 0 bytes, rt_memcpy_v6.o(.text))

[Called By]

- >> CDC_Receive_FS

__rt_memcpy (Thumb, 138 bytes, Stack size 0 bytes, rt_memcpy_v6.o(.text), UNUSED)

[Calls]

- >> __aeabi_memcpy4

_memcpy_lastbytes (Thumb, 0 bytes, Stack size unknown bytes, rt_memcpy_v6.o(.text), UNUSED)

__aeabi_memcpy4 (Thumb, 0 bytes, Stack size 8 bytes, rt_memcpy_w.o(.text))

[Stack]

- Max Depth = 8
- Call Chain = __aeabi_memcpy4

[Called By]

- >> HAL_PCD_Init
- >> __rt_memcpy

__aeabi_memcpy8 (Thumb, 0 bytes, Stack size 8 bytes, rt_memcpy_w.o(.text), UNUSED)

__rt_memcpy_w (Thumb, 100 bytes, Stack size 8 bytes, rt_memcpy_w.o(.text), UNUSED)

_memcpy_lastbytes_aligned (Thumb, 0 bytes, Stack size unknown bytes, rt_memcpy_w.o(.text), UNUSED)

__aeabi_memclr (Thumb, 0 bytes, Stack size 0 bytes, rt_memclr.o(.text))

[Called By]

- >> CDC_Receive_FS
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

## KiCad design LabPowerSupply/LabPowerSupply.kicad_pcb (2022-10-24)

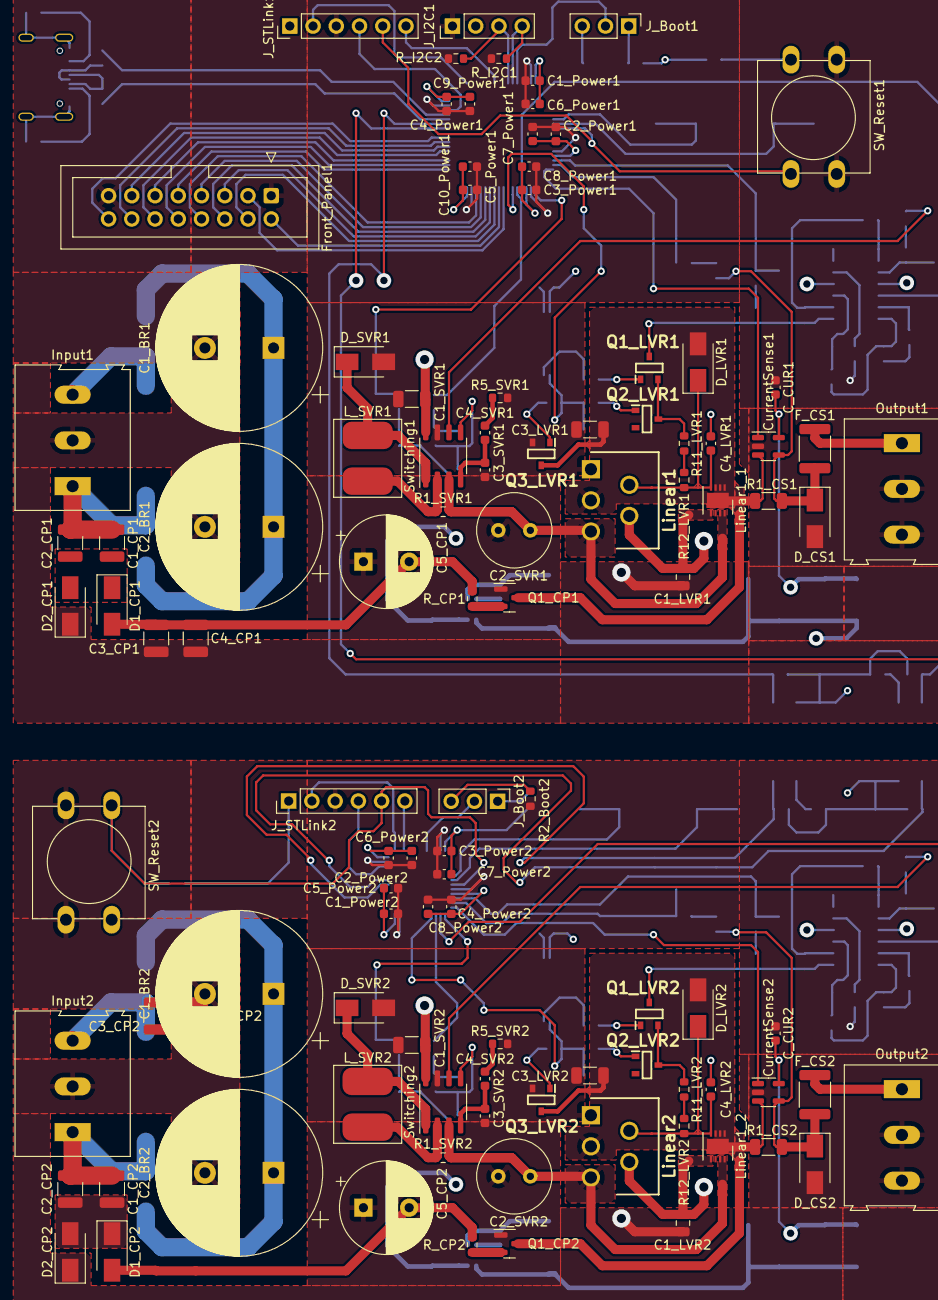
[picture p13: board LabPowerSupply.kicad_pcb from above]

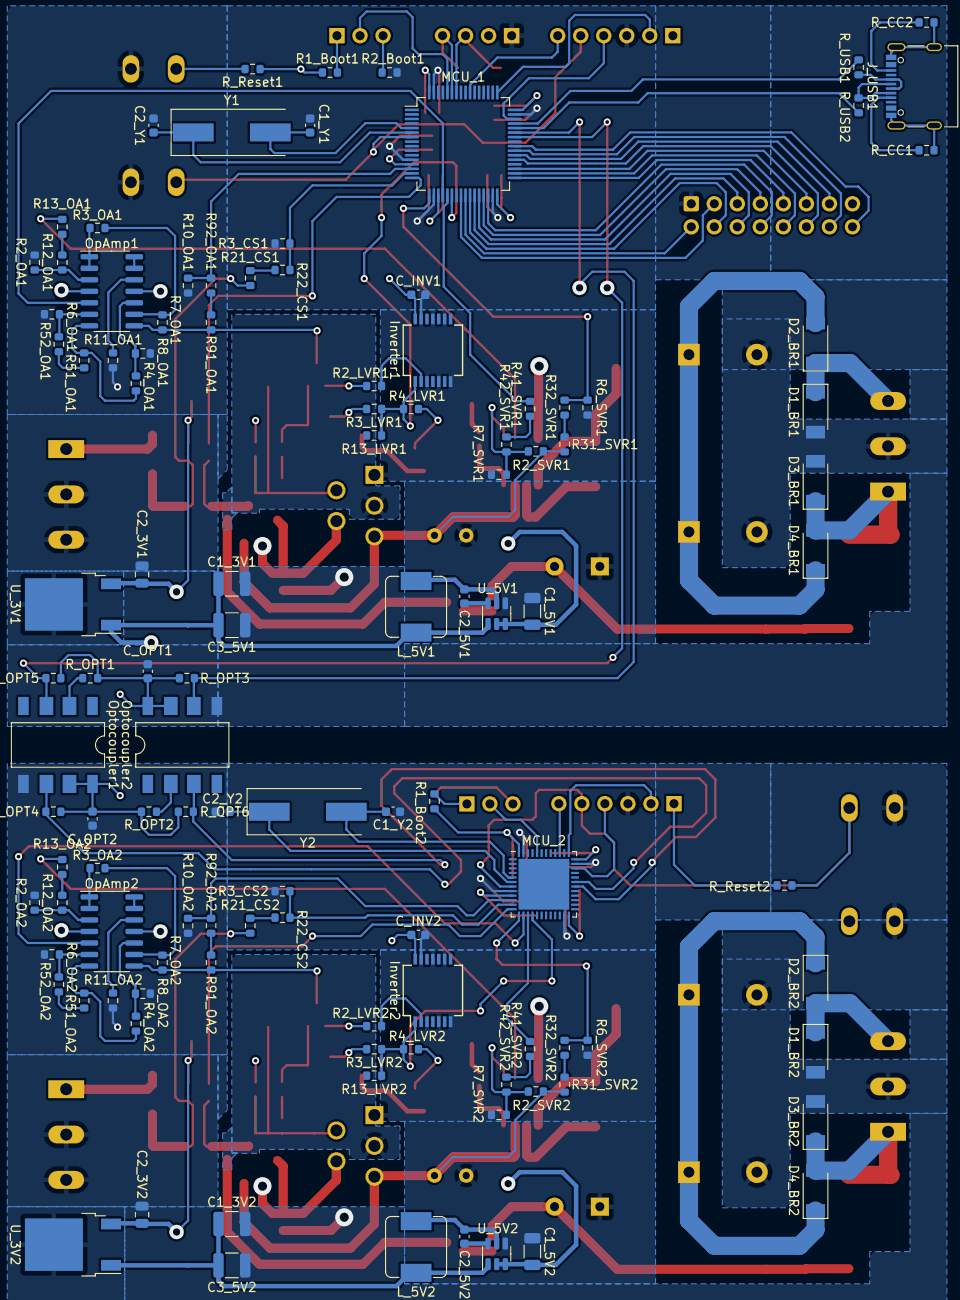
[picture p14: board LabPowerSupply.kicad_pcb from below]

Board: 4 copper layers, 219 parts (114 on the bottom side), 147 nets.

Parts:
C1_3V1, C1_3V2, C1_CP1, C1_CP2, C2_CP1, C2_CP2, C3_5V1, C3_5V2, C3_CP1, C3_CP2, C4_CP1, C4_CP2: 22u; C_1210_3225Metric
C1_5V1, C1_5V2, C1_SVR1, C1_SVR2, C3_LVR1, C3_LVR2: 10u; C_1206_3216Metric
C1_BR1, C1_BR2, C2_BR1, C2_BR2: 6.8m; CP_Radial_D18.0mm_P7.50mm
C1_LVR1, C1_LVR2: 4.7u; C_0805_2012Metric
C1_Power1, C1_Power2, C2_Power1, C2_Power2, C3_Power1, C3_Power2, C4_Power1, C4_Power2, C5_Power1: 1u; C_0603_1608Metric
C1_Y1, C1_Y2, C2_Y1, C2_Y2, C4_LVR1, C4_LVR2: 20p; C_0603_1608Metric
C2_3V1, C2_3V2: 2.2u; C_0805_2012Metric
C2_5V1, C2_5V2, C5_Power2, C6_Power1, C6_Power2, C7_Power1, C7_Power2, C8_Power1, C8_Power2, C9_Power1, C10_Power1: 100n; C_0603_1608Metric
C2_SVR1, C2_SVR2: 100u; C_Radial_D8.0mm_H7.0mm_P3.50mm
C3_SVR1, C3_SVR2: 22n; C_0603_1608Metric
C4_SVR1, C4_SVR2: 220p; C_0603_1608Metric
C5_CP1, C5_CP2: 1m; CP_Radial_D10.0mm_P5.00mm
C_CUR1, C_CUR2: 100n; C_0603_1608Metric
C_INV1, C_INV2: 100n; C_0603_1608Metric
C_OPT1, C_OPT2: 100n; C_0603_1608Metric
CurrentSense1, CurrentSense2: INA180A1; SOT-23-5
D1_BR1, D1_BR2, D2_BR1, D2_BR2, D3_BR1, D3_BR2, D4_BR1, D4_BR2: PMEG4050EP; D_SOD-128
D1_CP1, D1_CP2, D2_CP1, D2_CP2: 1N4001; D_SMA
D_CS1, D_CS2: 1N4001; D_SMA
D_LVR1, D_LVR2: 1N4001; D_SMA
D_SVR1, D_SVR2: 1N4001; D_SMA
F_CS1, F_CS2: 290m; Fuse_1812_4532Metric
Front_Panel1: Conn_02x08_Counter_Clockwise; IDC-Header_2x08_P2.54mm_Vertical
Input1, Input2: Screw_Terminal_01x03; TerminalBlock_Altech_AK300-3_P5.00mm
Inverter1, Inverter2: 74AHC04; SSOP-14_5.3x6.2mm_P0.65mm
J_Boot1, J_Boot2: Conn_01x03_Male; PinHeader_1x03_P2.54mm_Vertical
J_I2C1: Conn_01x04_Male; PinHeader_1x04_P2.54mm_Vertical
J_STLink1, J_STLink2: Conn_01x06_Male; PinHeader_1x06_P2.54mm_Vertical
J_USB1: USB_C_Receptacle_USB2.0; USB_C_Receptacle_Palconn_UTC16-G
L_5V1, L_5V2: 4.7u; L_Sumida_CDMC6D28_7.25x6.5mm
L_SVR1, L_SVR2: 22u; L_Sumida_CR75
Linear1, Linear2: LT3083ET#PBF; TO170P457X1022X2306-5P
Linear1_1, Linear1_2: LT3080xDD; DFN-8-1EP_3x3mm_P0.5mm_EP1.66x2.38mm
MCU_1: STM32L151R6TxA; LQFP-64_10x10mm_P0.5mm
MCU_2: STM32L100C6UxA; QFN-48-1EP_7x7mm_P0.5mm_EP5.6x5.6mm
OpAmp1, OpAmp2: LM324; SOIC-14_3.9x8.7mm_P1.27mm
Optocoupler1, Optocoupler2: 6N137; PowerIntegrations_SMD-8
Output1, Output2: Screw_Terminal_01x03; TerminalBlock_Altech_AK300-3_P5.00mm
Q1_CP1, Q1_CP2: FMMT495TA; SOT-23
Q1_LVR1, Q1_LVR2, Q2_LVR1, Q2_LVR2, Q3_LVR1, Q3_LVR2: PJA3404_R1_00001; SOT95P240X110-3N
R1_Boot1, R1_Boot2, R2_Boot1, R2_Boot2, R5_SVR1, R5_SVR2: 5.1k; R_0603_1608Metric
R1_CS1, R1_CS2: 300m; R_1206_3216Metric
R1_SVR1, R1_SVR2: 180m; R_0603_1608Metric
R2_LVR1, R2_LVR2, R2_OA1, R2_OA2, R3_CS1, R3_CS2, R3_LVR1, R3_LVR2, R3_OA1, R3_OA2, R4_LVR1, R4_LVR2, R4_OA1, R4_OA2, R6_OA1, R6_OA2, R6_SVR1, R6_SVR2, R7_OA1, R7_OA2, R8_OA1, R8_OA2, R10_OA1, R10_OA2, R22_CS1, R22_CS2, R92_OA1, R92_OA2: 1k; R_0603_1608Metric
R2_SVR1, R2_SVR2, R11_OA1, R11_OA2, R13_LVR1, R13_LVR2: 10k; R_0603_1608Metric
R7_SVR1, R7_SVR2, R41_SVR1, R41_SVR2, R42_SVR1, R42_SVR2: 1.2k; R_0603_1608Metric
R11_LVR1, R11_LVR2, R12_LVR1, R12_LVR2, R12_OA1, R12_OA2, R13_OA1, R13_OA2, R21_CS1, R21_CS2, R31_SVR1, R31_SVR2, R32_SVR1, R32_SVR2, R51_OA1, R51_OA2, R52_OA1, R52_OA2, R91_OA1, R91_OA2: 2k; R_0603_1608Metric
R_CC1, R_CC2: 5.1k; R_0603_1608Metric
R_CP1, R_CP2: 1k; R_0603_1608Metric
R_I2C1, R_I2C2: 4.7k; R_0603_1608Metric
R_OPT1, R_OPT2: 470; R_0603_1608Metric
R_OPT3, R_OPT4, R_OPT5, R_OPT6: 10k; R_0603_1608Metric
R_Reset1, R_Reset2: 1k; R_0603_1608Metric
R_USB1, R_USB2: 22; R_0603_1608Metric
SW_Reset1, SW_Reset2: SW_MEC_5G; SW_PUSH-12mm
Switching1, Switching2: L6902D; SO-8_3.9x4.9mm_P1.27mm
U_3V1, U_3V2: LP2950-3.3_TO252; TO-252-2
U_5V1, U_5V2: AP63205WU; TSOT-23-6
Y1, Y2: 8M; Crystal_SMD_HC49-SD

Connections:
+3.3V: C1_Power1.2, C2_3V1.1, C2_Power1.2, C3_Power1.2, C4_Power1.2, C5_Power1.2, C6_Power1.2, C7_Power1.2, C8_Power1.2, C9_Power1.2, C10_Power1.2, C_CUR1.2, C_INV1.2, C_OPT1.2, CurrentSense1.5 (V+), Inverter1.14 (VCC), J_STLink1.1, MCU_1.13 (VDDA), MCU_1.19 (VDD), MCU_1.32 (VDD), MCU_1.48 (VDD), MCU_1.64 (VDD), Optocoupler2.7 (EN), Optocoupler2.8 (VCC), R1_Boot1.2, R_OPT1.1, R_OPT3.2, R_OPT5.1, R_Reset1.1, U_3V1.3 (VO)
+3.3VA: C1_Power2.2, C2_3V2.1, C2_Power2.2, C3_Power2.2, C4_Power2.2, C5_Power2.2, C6_Power2.2, C7_Power2.2, C8_Power2.2, C_CUR2.2, C_INV2.2, C_OPT2.2, CurrentSense2.5 (V+), Inverter2.14 (VCC), J_STLink2.1, MCU_2.9 (VDDA), MCU_2.24 (VDD), MCU_2.36 (VDD), MCU_2.48 (VDD), Optocoupler1.7 (EN), Optocoupler1.8 (VCC), R1_Boot2.1, R_OPT2.2, R_OPT4.2, R_OPT6.2, R_Reset2.1, U_3V2.3 (VO)
/Channel 1 Power Rails/5 Volts: C1_3V1.2, C3_5V1.2, J_I2C1.2, L_5V1.2, U_3V1.1 (VI), U_5V1.1 (FB)
/Channel Power Supply 1/AC 1: D1_BR1.1 (K), D2_BR1.2 (A), Input1.3
/Channel Power Supply 1/AC 2: C1_CP1.1, C2_CP1.1, D3_BR1.1 (K), D4_BR1.2 (A), Input1.1
/Channel Power Supply 1/ADC 1: MCU_1.17 (PA3), R6_SVR1.1, R32_SVR1.2
/Channel Power Supply 1/ADC 2: MCU_1.14 (PA0), R10_OA1.1, R92_OA1.2
/Channel Power Supply 1/ADC 3: CurrentSense1.1, MCU_1.16 (PA2)
/Channel Power Supply 1/ADC 4: MCU_1.15 (PA1), R3_CS1.1, R22_CS1.2
/Channel Power Supply 1/Charge Pump/Charge: C3_LVR1.1, CurrentSense1.3 (+), D_LVR1.2 (A), Linear1.3 (OUT), Linear1_1.1 (OUT), Linear1_1.2 (OUT), Linear1_1.3 (OUT), Linear1_1.9 (OUT), Q1_CP1.3 (C), Q3_LVR1.3 (D), R1_CS1.1
/Channel Power Supply 1/Charge Pump/Negative: C3_CP1.1, C4_CP1.1, C5_CP1.2, D1_CP1.2 (A), OpAmp1.11 (V-), R_CP1.1
/Channel Power Supply 1/Current Sense /Output: CurrentSense1.4 (-), D_CS1.1 (K), F_CS1.1, R1_CS1.2, R21_CS1.1
/Channel Power Supply 1/DAC 1: MCU_1.21 (PA5), R41_SVR1.2
/Channel Power Supply 1/DAC 2: MCU_1.20 (PA4), OpAmp1.5 (+)
/Channel Power Supply 1/Differential Op-Amp Circuit/3.3 Volts: R13_OA1.1, Switching1.6 (VREF)
/Channel Power Supply 1/Differential Op-Amp Circuit/Set Voltage: OpAmp1.8, Q1_LVR1.3 (D), R7_OA1.2, R91_OA1.1
/Channel Power Supply 1/Linear Voltage Regulator /Linear Input: C2_SVR1.1, Linear1.5 (IN), Linear1_1.7 (IN), Linear1_1.8 (IN), R1_SVR1.2, R2_SVR1.1, R31_SVR1.1, Switching1.3 (CS-)
/Channel Power Supply 1/On/Off: Inverter1.1, MCU_1.22 (PA6), R3_LVR1.2, R4_LVR1.2, R13_LVR1.2
/Channel Power Supply 1/Switching Voltage Regulator/FeedBack: R2_SVR1.2, R7_SVR1.2, R42_SVR1.1, Switching1.5 (FB)
/Channel Power Supply 2/AC 1: D1_BR2.1 (K), D2_BR2.2 (A), Input2.3
/Channel Power Supply 2/AC 2: C1_CP2.1, C2_CP2.1, D3_BR2.1 (K), D4_BR2.2 (A), Input2.1
/Channel Power Supply 2/ADC 1: MCU_2.13 (PA3), R6_SVR2.1, R32_SVR2.2
/Channel Power Supply 2/ADC 2: MCU_2.10 (PA0), R10_OA2.1, R92_OA2.2
/Channel Power Supply 2/ADC 3: CurrentSense2.1, MCU_2.12 (PA2)
/Channel Power Supply 2/ADC 4: MCU_2.11 (PA1), R3_CS2.1, R22_CS2.2
/Channel Power Supply 2/Charge Pump/Charge: C3_LVR2.1, CurrentSense2.3 (+), D_LVR2.2 (A), Linear1_2.1 (OUT), Linear1_2.2 (OUT), Linear1_2.3 (OUT), Linear1_2.9 (OUT), Linear2.3 (OUT), Q1_CP2.3 (C), Q3_LVR2.3 (D), R1_CS2.1
/Channel Power Supply 2/Charge Pump/Negative: C3_CP2.1, C4_CP2.1, C5_CP2.2, D1_CP2.2 (A), OpAmp2.11 (V-), R_CP2.1
/Channel Power Supply 2/Current Sense /Output: CurrentSense2.4 (-), D_CS2.1 (K), F_CS2.1, R1_CS2.2, R21_CS2.1
/Channel Power Supply 2/DAC 1: MCU_2.15 (PA5), R41_SVR2.2
/Channel Power Supply 2/DAC 2: MCU_2.14 (PA4), OpAmp2.5 (+)
/Channel Power Supply 2/Differential Op-Amp Circuit/3.3 Volts: R13_OA2.1, Switching2.6 (VREF)
/Channel Power Supply 2/Differential Op-Amp Circuit/Set Voltage: OpAmp2.8, Q1_LVR2.3 (D), R7_OA2.2, R91_OA2.1
/Channel Power Supply 2/Linear Voltage Regulator /Linear Input: C2_SVR2.1, Linear1_2.7 (IN), Linear1_2.8 (IN), Linear2.5 (IN), R1_SVR2.2, R2_SVR2.1, R31_SVR2.1, Switching2.3 (CS-)
/Channel Power Supply 2/On/Off: Inverter2.1, MCU_2.16 (PA6), R3_LVR2.2, R4_LVR2.2, R13_LVR2.2
/Channel Power Supply 2/Switching Voltage Regulator/FeedBack: R2_SVR2.2, R7_SVR2.2, R42_SVR2.1, Switching2.5 (FB)
/Optocouplers/RX 1: MCU_1.43 (PA10), Optocoupler2.6 (VO), R_OPT3.1
/Optocouplers/RX 2: MCU_2.31 (PA10), Optocoupler1.6 (VO), R_OPT4.1
/Optocouplers/TX1: MCU_1.42 (PA9), Optocoupler1.3 (C), R_OPT5.2
/Optocouplers/TX 2: MCU_2.30 (PA9), Optocoupler2.3 (C), R_OPT6.1
/Primary Controller/I2C SCL: J_I2C1.4, MCU_1.59 (PB7), R_I2C1.1
/Primary Controller/I2C SDA: J_I2C1.3, MCU_1.58 (PB6), R_I2C2.1
/Primary Controller/SWO: J_STLink1.6, MCU_1.55 (PB3)
/Primary Controller/SW_CLK: J_STLink1.2, MCU_1.49 (PA14)
/Primary Controller/SW_DIO: J_STLink1.4, MCU_1.46 (PA13)
GND1: C1_3V1.1, C1_5V1.1, C1_BR1.2, C1_LVR1.1, C1_Power1.1, C1_SVR1.2, C1_Y1.1, C2_3V1.2, C2_BR1.2, C2_Power1.1, C2_SVR1.2, C2_Y1.1, C3_5V1.1, C3_CP1.2, C3_LVR1.2, C3_Power1.1, C3_SVR1.2, C4_CP1.2, C4_LVR1.2, C4_Power1.1, C5_CP1.1, C5_Power1.1, C6_Power1.1, C7_Power1.1, C8_Power1.1, C9_Power1.1, C10_Power1.1, C_CUR1.1, C_INV1.1, C_OPT1.1, CurrentSense1.2 (GND), D1_BR1.2 (A), D2_CP1.1 (K), D3_BR1.2 (A), D_CS1.2 (A), D_SVR1.2 (A), Front_Panel1.1, Front_Panel1.15, Input1.2, Inverter1.3, Inverter1.5, Inverter1.7 (GND), Inverter1.9, Inverter1.11, Inverter1.13, J_I2C1.1, J_STLink1.3, Linear1.1 (NC), MCU_1.12 (VSSA), MCU_1.18 (VSS), MCU_1.31 (VSS), MCU_1.47 (VSS), MCU_1.63 (VSS), Optocoupler2.5 (GND), Output1.2, Output1.3, Q1_CP1.2 (B), Q2_LVR1.2 (S), Q3_LVR1.2 (S), R2_Boot1.2, R2_OA1.2, R3_CS1.2, R5_SVR1.2, R6_OA1.2, R6_SVR1.2, R7_SVR1.1, R8_OA1.2, R10_OA1.2, R11_OA1.1, R13_LVR1.1, R_I2C1.2, R_I2C2.2, SW_Reset1.1, Switching1.7 (GND), U_3V1.2 (GND), U_5V1.4 (GND)
GND2: C1_3V2.1, C1_5V2.1, C1_BR2.2, C1_LVR2.1, C1_Power2.1, C1_SVR2.2, C1_Y2.1, C2_3V2.2, C2_BR2.2, C2_Power2.1, C2_SVR2.2, C2_Y2.1, C3_5V2.1, C3_CP2.2, C3_LVR2.2, C3_Power2.1, C3_SVR2.2, C4_CP2.2, C4_LVR2.2, C4_Power2.1, C5_CP2.1, C5_Power2.1, C6_Power2.1, C7_Power2.1, C8_Power2.1, C_CUR2.1, C_INV2.1, C_OPT2.1, CurrentSense2.2 (GND), D1_BR2.2 (A), D2_CP2.1 (K), D3_BR2.2 (A), D_CS2.2 (A), D_SVR2.2 (A), Input2.2, Inverter2.3, Inverter2.5, Inverter2.7 (GND), Inverter2.9, Inverter2.11, Inverter2.13, J_STLink2.3, Linear2.1 (NC), MCU_2.8 (VSSA), MCU_2.23 (VSS), MCU_2.35 (VSS), MCU_2.47 (VSS), MCU_2.49 (VSS), Optocoupler1.5 (GND), Output2.2, Output2.3, Q1_CP2.2 (B), Q2_LVR2.2 (S), Q3_LVR2.2 (S), R2_Boot2.2, R2_OA2.2, R3_CS2.2, R5_SVR2.2, R6_OA2.2, R6_SVR2.2, R7_SVR2.1, R8_OA2.2, R10_OA2.2, R11_OA2.1, R13_LVR2.1, SW_Reset2.1, Switching2.7 (GND), U_3V2.2 (GND), U_5V2.4 (GND)
unnamed: C1_3V2.2, C3_5V2.2, L_5V2.2, U_3V2.1 (VI), U_5V2.1 (FB)
unnamed: C1_CP1.2, C2_CP1.2, D1_CP1.1 (K), D2_CP1.2 (A)
unnamed: C1_CP2.2, C2_CP2.2, D1_CP2.1 (K), D2_CP2.2 (A)
unnamed: C1_Y1.2, MCU_1.5 (PH0), Y1.2
unnamed: C1_Y2.2, MCU_2.5 (PH0), Y2.2
unnamed: C2_5V1.1, L_5V1.1, U_5V1.5 (SW)
unnamed: C2_5V1.2, U_5V1.6 (BST)
unnamed: C2_5V2.1, L_5V2.1, U_5V2.5 (SW)
unnamed: C2_5V2.2, U_5V2.6 (BST)
unnamed: C2_Y1.2, MCU_1.6 (PH1), Y1.1
unnamed: C2_Y2.2, MCU_2.6 (PH1), Y2.1
unnamed: C3_SVR1.1, C4_SVR1.1, Switching1.4 (COMP)
unnamed: C3_SVR2.1, C4_SVR2.1, Switching2.4 (COMP)
unnamed: C4_LVR1.1, D_LVR1.1 (K), Linear1.2 (SET), Linear1_1.4 (SET), R12_LVR1.1
unnamed: C4_LVR2.1, D_LVR2.1 (K), Linear1_2.4 (SET), Linear2.2 (SET), R12_LVR2.1
unnamed: C4_SVR1.2, R5_SVR1.1
unnamed: C4_SVR2.2, R5_SVR2.1
unnamed: D_SVR1.1 (K), L_SVR1.1, Switching1.1 (OUT)
unnamed: D_SVR2.1 (K), L_SVR2.1, Switching2.1 (OUT)
unnamed: F_CS1.2, Output1.1
unnamed: F_CS2.2, Output2.1
unnamed: Front_Panel1.2, MCU_1.25 (PC5)
unnamed: Front_Panel1.3, MCU_1.24 (PC4)
unnamed: Front_Panel1.4, MCU_1.26 (PB0)
unnamed: Front_Panel1.5, MCU_1.27 (PB1)
unnamed: Front_Panel1.6, MCU_1.28 (PB2)
unnamed: Front_Panel1.7, MCU_1.29 (PB10)
unnamed: Front_Panel1.8, MCU_1.30 (PB11)
unnamed: Front_Panel1.9, MCU_1.33 (PB12)
unnamed: Front_Panel1.10, MCU_1.34 (PB13)
unnamed: Front_Panel1.11, MCU_1.35 (PB14)
unnamed: Front_Panel1.12, MCU_1.37 (PC6)
unnamed: Front_Panel1.13, MCU_1.38 (PC7)
unnamed: Front_Panel1.14, MCU_1.39 (PC8)
unnamed: Front_Panel1.16, MCU_1.40 (PC9)
unnamed: Inverter1.2, R2_LVR1.2
unnamed: Inverter2.2, R2_LVR2.2
unnamed: J_Boot1.1, R1_Boot1.1
unnamed: J_Boot1.2, MCU_1.60 (BOOT0)
unnamed: J_Boot1.3, R2_Boot1.1
unnamed: J_Boot2.1, R1_Boot2.2
unnamed: J_Boot2.2, MCU_2.44 (BOOT0)
unnamed: J_Boot2.3, R2_Boot2.1
unnamed: J_STLink1.5, MCU_1.7 (NRST), R_Reset1.2, SW_Reset1.2
unnamed: J_STLink2.2, MCU_2.37 (PA14)
unnamed: J_STLink2.4, MCU_2.34 (PA13)
unnamed: J_STLink2.5, MCU_2.7 (NRST), R_Reset2.2, SW_Reset2.2
unnamed: J_STLink2.6, MCU_2.39 (PB3)
unnamed: J_USB1.A1 (GND), J_USB1.A12 (GND), J_USB1.B1 (GND), J_USB1.B12 (GND), J_USB1.S1 (SHIELD), R_CC1.2, R_CC2.2
unnamed: J_USB1.A5 (CC1), R_CC1.1
unnamed: J_USB1.A6 (D+), J_USB1.B6 (D+), R_USB1.2
unnamed: J_USB1.A7 (D-), J_USB1.B7 (D-), R_USB2.2
unnamed: J_USB1.B5 (CC2), R_CC2.1
unnamed: L_SVR1.2, R1_SVR1.1, Switching1.2 (CS+)
unnamed: L_SVR2.2, R1_SVR2.1, Switching2.2 (CS+)
unnamed: MCU_1.44 (PA11), R_USB2.1
unnamed: MCU_1.45 (PA12), R_USB1.1
unnamed: OpAmp1.1, OpAmp1.2 (-), R3_OA1.1
unnamed: OpAmp1.3 (+), R2_OA1.1, R12_OA1.2
unnamed: OpAmp1.6 (-), R6_OA1.1, R52_OA1.2
unnamed: OpAmp1.7, R4_OA1.1, R51_OA1.1
unnamed: OpAmp1.9 (-), R3_OA1.2, R7_OA1.1
unnamed: OpAmp1.10 (+), R4_OA1.2, R8_OA1.1
unnamed: OpAmp1.12 (+), R11_OA1.2
unnamed: OpAmp1.13 (-), OpAmp1.14
unnamed: OpAmp2.1, OpAmp2.2 (-), R3_OA2.1
unnamed: OpAmp2.3 (+), R2_OA2.1, R12_OA2.2
unnamed: OpAmp2.6 (-), R6_OA2.1, R52_OA2.2
unnamed: OpAmp2.7, R4_OA2.1, R51_OA2.1
unnamed: OpAmp2.9 (-), R3_OA2.2, R7_OA2.1
unnamed: OpAmp2.10 (+), R4_OA2.2, R8_OA2.1
unnamed: OpAmp2.12 (+), R11_OA2.2
unnamed: OpAmp2.13 (-), OpAmp2.14
unnamed: Optocoupler1.2 (A), R_OPT1.2
unnamed: Optocoupler2.2 (A), R_OPT2.1
unnamed: Q1_CP1.1 (E), R_CP1.2
unnamed: Q1_CP2.1 (E), R_CP2.2
unnamed: Q1_LVR1.1 (G), R2_LVR1.1
unnamed: Q1_LVR1.2 (S), Q2_LVR1.3 (D), R11_LVR1.2
unnamed: Q1_LVR2.1 (G), R2_LVR2.1
unnamed: Q1_LVR2.2 (S), Q2_LVR2.3 (D), R11_LVR2.2
unnamed: Q2_LVR1.1 (G), R3_LVR1.1
unnamed: Q2_LVR2.1 (G), R3_LVR2.1
unnamed: Q3_LVR1.1 (G), R4_LVR1.1
unnamed: Q3_LVR2.1 (G), R4_LVR2.1
unnamed: R11_LVR1.1, R12_LVR1.2
unnamed: R11_LVR2.1, R12_LVR2.2
unnamed: R12_OA1.1, R13_OA1.2
unnamed: R12_OA2.1, R13_OA2.2
unnamed: R21_CS1.2, R22_CS1.1
unnamed: R21_CS2.2, R22_CS2.1
unnamed: R31_SVR1.2, R32_SVR1.1
unnamed: R31_SVR2.2, R32_SVR2.1
unnamed: R41_SVR1.1, R42_SVR1.2
unnamed: R41_SVR2.1, R42_SVR2.2
unnamed: R51_OA1.2, R52_OA1.1
unnamed: R51_OA2.2, R52_OA2.1
unnamed: R91_OA1.2, R92_OA1.1
unnamed: R91_OA2.2, R92_OA2.1
VCC: C1_5V1.2, C1_BR1.1, C1_LVR1.2, C1_SVR1.1, C2_BR1.1, D2_BR1.1 (K), D4_BR1.1 (K), Linear1.4 (VCONTROL), Linear1_1.5 (VCONTROL), OpAmp1.4 (V+), Switching1.8 (VCC), U_5V1.2 (EN), U_5V1.3 (IN)
VDD: C1_5V2.2, C1_BR2.1, C1_LVR2.2, C1_SVR2.1, C2_BR2.1, D2_BR2.1 (K), D4_BR2.1 (K), Linear1_2.5 (VCONTROL), Linear2.4 (VCONTROL), OpAmp2.4 (V+), Switching2.8 (VCC), U_5V2.2 (EN), U_5V2.3 (IN)

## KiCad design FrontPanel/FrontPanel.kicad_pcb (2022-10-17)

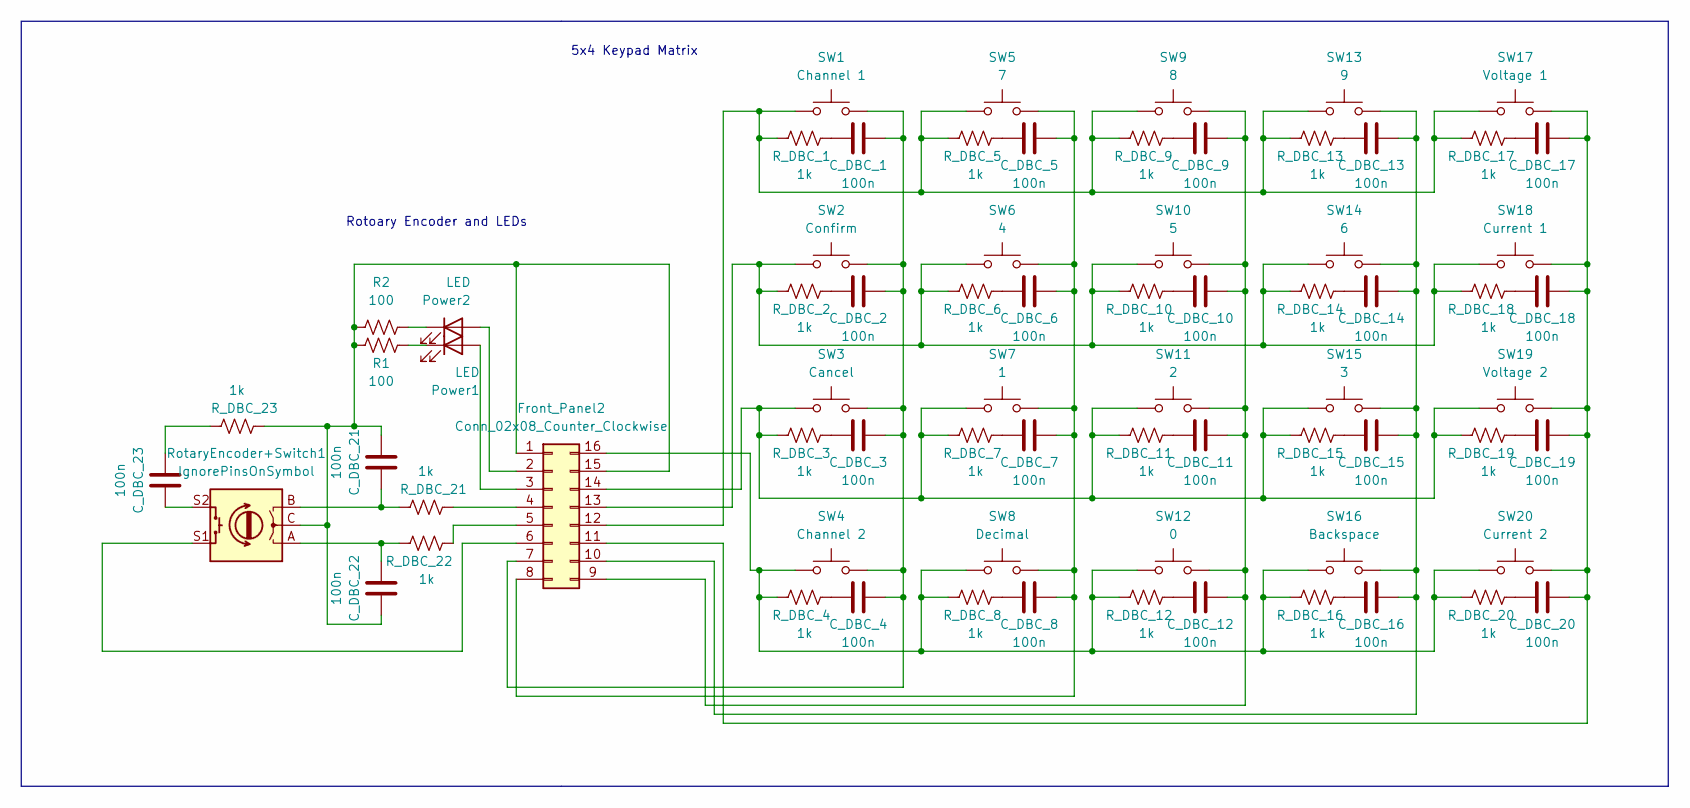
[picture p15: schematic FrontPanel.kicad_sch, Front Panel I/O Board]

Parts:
C_DBC_1, C_DBC_2, C_DBC_3, C_DBC_4, C_DBC_5, C_DBC_6, C_DBC_7, C_DBC_8, C_DBC_9, C_DBC_10, C_DBC_11, C_DBC_12, C_DBC_13, C_DBC_14, C_DBC_15, C_DBC_16, C_DBC_17, C_DBC_18, C_DBC_19, C_DBC_20, C_DBC_21, C_DBC_22, C_DBC_23: 100n; C_0603_1608Metric
Front_Panel2: Conn_02x08_Counter_Clockwise; IDC-Header_2x08_P2.54mm_Vertical
Power1, Power2: LED; LED_0603_1608Metric
R1, R2: 100; R_0603_1608Metric
R_DBC_1, R_DBC_2, R_DBC_3, R_DBC_4, R_DBC_5, R_DBC_6, R_DBC_7, R_DBC_8, R_DBC_9, R_DBC_10, R_DBC_11, R_DBC_12, R_DBC_13, R_DBC_14, R_DBC_15, R_DBC_16, R_DBC_17, R_DBC_18, R_DBC_19, R_DBC_20, R_DBC_21, R_DBC_22, R_DBC_23: 1k; R_0603_1608Metric
RotaryEncoder+Switch1: IgnorePinsOnSymbol; RotaryEncoder_Alps_EC11E-Switch_Vertical_H20mm
SW1: Channel 1; SW_PUSH-12mm
SW2: Confirm; SW_PUSH-12mm
SW3: Cancel; SW_PUSH-12mm
SW4: Channel 2; SW_PUSH-12mm
SW5: 7; SW_PUSH-12mm
SW6: 4; SW_PUSH-12mm
SW7: 1; SW_PUSH-12mm
SW8: Decimal; SW_PUSH-12mm
SW9: 8; SW_PUSH-12mm
SW10: 5; SW_PUSH-12mm
SW11: 2; SW_PUSH-12mm
SW12: 0; SW_PUSH-12mm
SW13: 9; SW_PUSH-12mm
SW14: 6; SW_PUSH-12mm
SW15: 3; SW_PUSH-12mm
SW16: Backspace; SW_PUSH-12mm
SW17: Voltage 1; SW_PUSH-12mm
SW18: Current 1; SW_PUSH-12mm
SW19: Voltage 2; SW_PUSH-12mm
SW20: Current 2; SW_PUSH-12mm

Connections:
unnamed: C_DBC_1.1, R_DBC_1.2
unnamed: C_DBC_1.2, C_DBC_2.2, C_DBC_3.2, C_DBC_4.2, Front_Panel2.7, SW1.2, SW2.2, SW3.2, SW4.2
unnamed: C_DBC_2.1, R_DBC_2.2
unnamed: C_DBC_3.1, R_DBC_3.2
unnamed: C_DBC_4.1, R_DBC_4.2
unnamed: C_DBC_5.1, R_DBC_5.2
unnamed: C_DBC_5.2, C_DBC_6.2, C_DBC_7.2, C_DBC_8.2, Front_Panel2.8, SW5.2, SW6.2, SW7.2, SW8.2
unnamed: C_DBC_6.1, R_DBC_6.2
unnamed: C_DBC_7.1, R_DBC_7.2
unnamed: C_DBC_8.1, R_DBC_8.2
unnamed: C_DBC_9.1, R_DBC_9.2
unnamed: C_DBC_10.1, R_DBC_10.2
unnamed: C_DBC_9.2, C_DBC_10.2, C_DBC_11.2, C_DBC_12.2, Front_Panel2.9, SW9.2, SW10.2, SW11.2, SW12.2
unnamed: C_DBC_11.1, R_DBC_11.2
unnamed: C_DBC_12.1, R_DBC_12.2
unnamed: C_DBC_13.1, R_DBC_13.2
unnamed: C_DBC_13.2, C_DBC_14.2, C_DBC_15.2, C_DBC_16.2, Front_Panel2.10, SW13.2, SW14.2, SW15.2, SW16.2
unnamed: C_DBC_14.1, R_DBC_14.2
unnamed: C_DBC_15.1, R_DBC_15.2
unnamed: C_DBC_16.1, R_DBC_16.2
unnamed: C_DBC_17.1, R_DBC_17.2
unnamed: C_DBC_18.1, R_DBC_18.2
unnamed: C_DBC_19.1, R_DBC_19.2
unnamed: C_DBC_20.1, R_DBC_20.2
unnamed: C_DBC_21.1, C_DBC_22.2, Front_Panel2.1, Front_Panel2.15, R1.2, R2.2, R_DBC_23.1, RotaryEncoder+Switch1.C
unnamed: C_DBC_21.2, R_DBC_21.2, RotaryEncoder+Switch1.B
unnamed: C_DBC_22.1, R_DBC_22.1, RotaryEncoder+Switch1.A
unnamed: C_DBC_23.1, R_DBC_23.2
unnamed: C_DBC_23.2, RotaryEncoder+Switch1.S2
unnamed: Front_Panel2.2, Power2.2 (A)
unnamed: Front_Panel2.3, Power1.2 (A)
unnamed: Front_Panel2.4, R_DBC_21.1
unnamed: Front_Panel2.5, R_DBC_22.2
unnamed: Front_Panel2.6, RotaryEncoder+Switch1.S1
unnamed: C_DBC_17.2, C_DBC_18.2, C_DBC_19.2, C_DBC_20.2, Front_Panel2.11, SW17.2, SW18.2, SW19.2, SW20.2
unnamed: Power1.1 (K), R1.1
unnamed: Power2.1 (K), R2.1
unnamed: Front_Panel2.12, R_DBC_1.1, R_DBC_5.1, R_DBC_9.1, R_DBC_13.1, R_DBC_17.1, SW1.1, SW5.1, SW9.1, SW13.1, SW17.1
unnamed: Front_Panel2.13, R_DBC_2.1, R_DBC_6.1, R_DBC_10.1, R_DBC_14.1, R_DBC_18.1, SW2.1, SW6.1, SW10.1, SW14.1, SW18.1
unnamed: Front_Panel2.14, R_DBC_3.1, R_DBC_7.1, R_DBC_11.1, R_DBC_15.1, R_DBC_19.1, SW3.1, SW7.1, SW11.1, SW15.1, SW19.1
unnamed: Front_Panel2.16, R_DBC_4.1, R_DBC_8.1, R_DBC_12.1, R_DBC_16.1, R_DBC_20.1, SW4.1, SW8.1, SW12.1, SW16.1, SW20.1

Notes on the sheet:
Rotoary Encoder and LEDs
5x4 Keypad Matrix

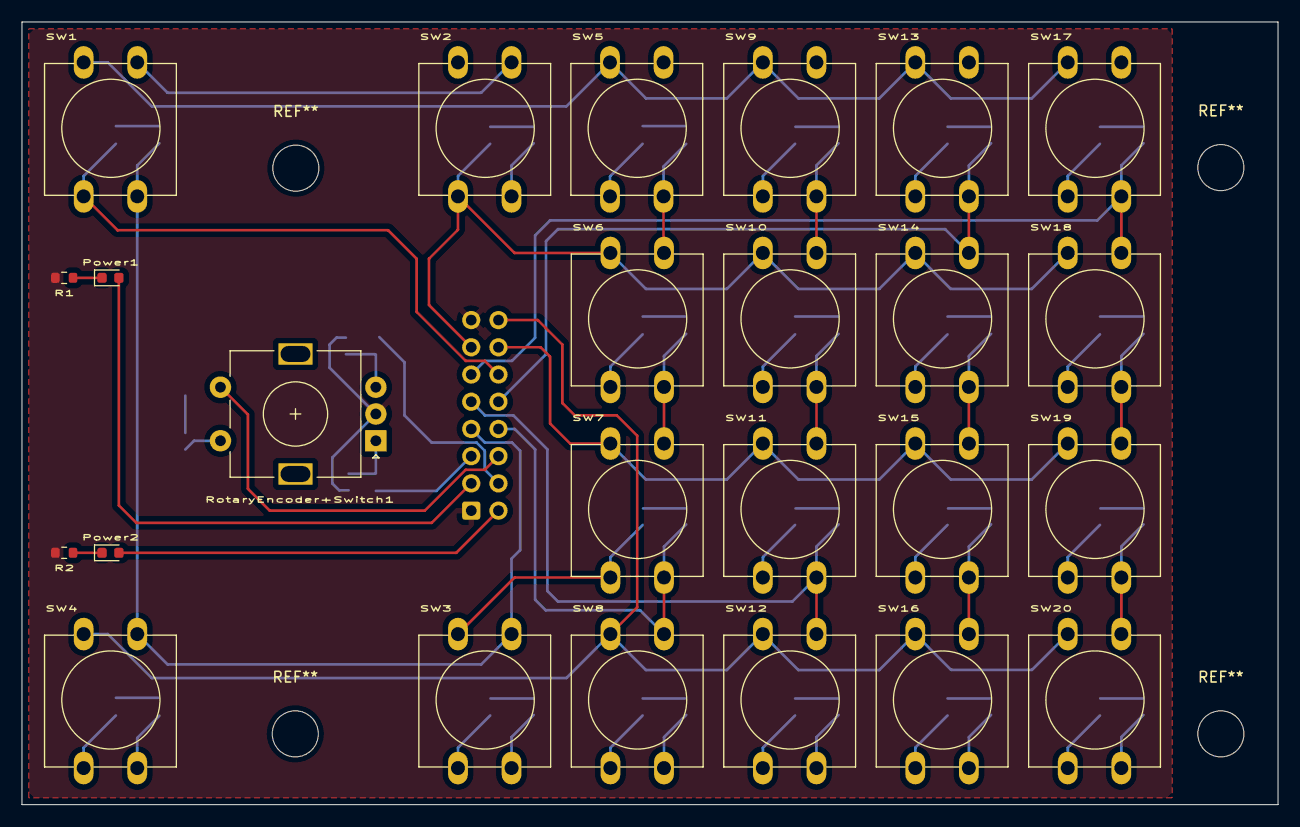
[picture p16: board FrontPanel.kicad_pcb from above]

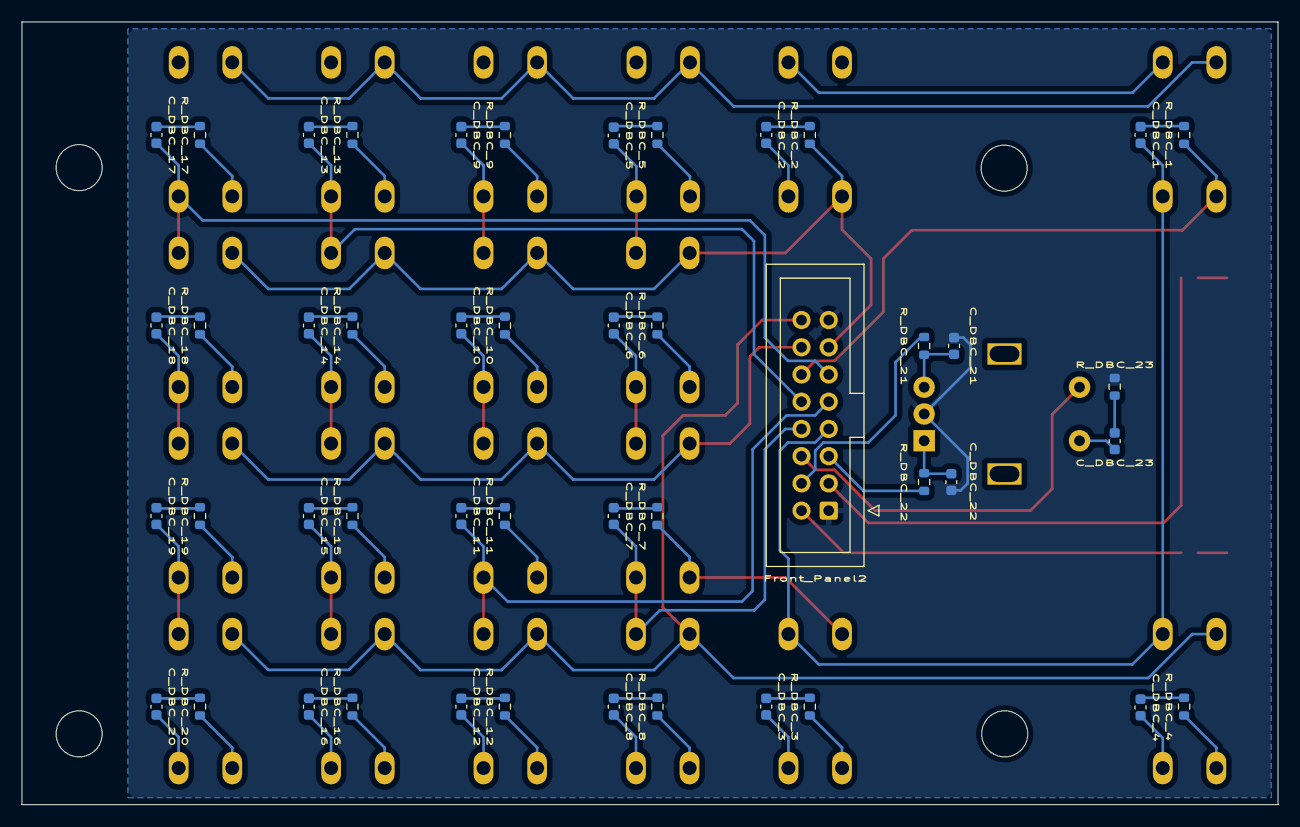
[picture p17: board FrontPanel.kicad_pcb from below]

Board: 2 copper layers, 117.2 x 73.0 mm, 72 parts (47 on the bottom side), 41 nets.

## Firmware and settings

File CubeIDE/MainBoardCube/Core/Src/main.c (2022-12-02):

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
/* Includes ------------------------------------------------------------------*/
#include "main.h"
#include "usb_device.h"

/* USER CODE BEGIN Includes */
#include "usbd_cdc_if.h"
#include "string.h"
#include "stdio.h"
#include "stdlib.h"
/* USER CODE END Includes */

/* USER CODE BEGIN PTD */
typedef enum ROTARY_STATE {NOTURN, CWTURN, CCWTURN} ROTARY_STATE;
typedef enum KEYPAD_ENUM {WAIT, V1, A1, V2, A2} KEYPAD_ENUM;
/* USER CODE END PTD */

/* USER CODE BEGIN PD */

/* LCD Section Begin ---------------------------------------------------------*/
#define SLAVE_ADDRESS_LCD 0x4E // change this according to your setup

//Char 0 = Right Arrow
//Char 1 = Vertical Line
const uint8_t customChar[64] = {
	0x08,0x04,0x02,0x1F,0x02,0x04,0x08,0x00, //Custom Char 0
	0x04,0x04,0x04,0x4,0x04,0x04,0x04,0x04,  //Custom Char 1
	0x00,0x00,0x00,0x0,0x00,0x00,0x00,0x00,  //Custom Char 2
	0x00,0x00,0x00,0x0,0x00,0x00,0x00,0x00,  //Custom Char 3
	0x00,0x00,0x00,0x0,0x00,0x00,0x00,0x00,  //Custom Char 4
	0x00,0x00,0x00,0x0,0x00,0x00,0x00,0x00,  //Custom Char 5
	0x00,0x00,0x00,0x0,0x00,0x00,0x00,0x00,  //Custom Char 6
	0x00,0x00,0x00,0x0,0x00,0x00,0x00,0x00   //Custom Char 7
};
/* LCD Section End -----------------------------------------------------------*/

/* ADC Section Begin ---------------------------------------------------------*/
#define ADC_OPAMP adc_values_cpy[0]
#define ADC_LINEAR adc_values_cpy[1]
#define ADC_CURRENT adc_values_cpy[2]
#define ADC_SWITCHING adc_values_cpy[3]
#define ADC_VREF adc_values_cpy[4]
/* ADC Section End -----------------------------------------------------------*/

/* PID Control for the Linear Voltage Regulator ------------------------------*/
#define P 0.01
#define I 0.01
#define D 0.0
/* PID Linear Section End ----------------------------------------------------*/

/* USER CODE END PD */

ADC_HandleTypeDef hadc;
DMA_HandleTypeDef hdma_adc;

DAC_HandleTypeDef hdac;

I2C_HandleTypeDef hi2c1;

TIM_HandleTypeDef htim2;
TIM_HandleTypeDef htim3;
TIM_HandleTypeDef htim4;
TIM_HandleTypeDef htim9;
TIM_HandleTypeDef htim10;
TIM_HandleTypeDef htim11;

UART_HandleTypeDef huart1;
DMA_HandleTypeDef hdma_usart1_rx;
DMA_HandleTypeDef hdma_usart1_tx;

/* USER CODE BEGIN PV */

/* USB Section Begin ---------------------------------------------------------*/
EXTI_HandleTypeDef hexti1;
uint8_t usbbuffer[64];//Usb buffer
/*
 * We need to be able to store USB commands and process them later because we may receive them too fast
 * We really only need to be able to store up to two commands, one for the write, and one for the read
 * We have enough ram left for a slightly bigger buffer though
 * A circular buffer would make sense for this but I'm lazy so here's your circular buffer
 */
#define CIRCSIZE 8
uint8_t notacircbuff[CIRCSIZE][64];
int8_t headiter = 1;//Start at element 1, we're not going to let the tailiter pass the headiter
int8_t tailiter = 0;
uint8_t MSG[64];
/* USB Section End -----------------------------------------------------------*/

/* UART Section Begin --------------------------------------------------------*/
uint8_t txbuffer[64];//Uart TX Buffer
uint8_t txbuffer_cpy[64];//Uart TX Buffer copy because transfer is circular
uint8_t rxbuffer[64];//Uart RX Buffer
/* UART Section End ----------------------------------------------------------*/

/* Keypad Section Begin ------------------------------------------------------*/
volatile int rowpin = -1;
uint8_t kpedge = 1;	//0 == falling edge 1 == rising edge
uint8_t swedge = 1;	//0 == falling edge 1 == rising edge

const uint8_t keypadlength = 5;
char keypadarr[5] = {'z','z','z','z','z'};//z is null
int8_t keypaditerator = 4;
uint8_t keypaddecimal = 0;
KEYPAD_ENUM kpenum = WAIT;
ROTARY_STATE rotenum = NOTURN;
uint8_t encmode = 0;
int8_t encpos = 0;

//static GPIO_TypeDef* row_ports[5] = { Row_1_GPIO_Port, Row_2_GPIO_Port, Row_3_GPIO_Port, Row_4_GPIO_Port, Row_5_GPIO_Port };
static uint16_t row_pins[5] = {Row_1_Pin, Row_2_Pin, Row_3_Pin, Row_4_Pin, Row_5_Pin};
static GPIO_TypeDef *col_ports[4] = { Col_1_GPIO_Port, Col_2_GPIO_Port, Col_3_GPIO_Port, Col_4_GPIO_Port };
static uint16_t col_pins[4] = { Col_1_Pin, Col_2_Pin, Col_3_Pin, Col_4_Pin };
static const char keypad_labels[5][4] = {
	{ '*', '+', '-', '/' },
	{ '1', '4', '7', '.' },
	{ '2', '5', '8', '0' },
	{ '3', '6', '9', '#' },
	{ 'A', 'B', 'C', 'D' }
};
/* Keypad Section End --------------------------------------------------------*/

//Channel numbers
volatile float volt_set_main = 0.0;
volatile float amp_set_main = 0.0;
volatile float volt_set_aux = 0.0;
volatile float amp_set_aux = 0.0;

volatile float volt_set_main_old = 0.0;
volatile float amp_set_main_old = 0.0;
//volatile float volt_set_aux_old = 0.0;
//volatile float amp_set_aux_old = 0.0;

volatile float op_num_old = 0.0;

//Array for the adc values and vars to hold them
volatile uint16_t adc_values[6];
uint16_t adc_values_cpy[6];
uint16_t* vrefptr = ((uint16_t*)VREFINT_CAL_ADDR_CMSIS);
volatile int8_t chstat_main = 0;
volatile int8_t chstat_aux_tx = 0;
volatile int8_t chstat_aux_rx = 0;
volatile uint8_t toggle_chstat_main = 0;
volatile uint8_t toggle_chstat_aux = 0;
volatile uint8_t toggle_chstat_main_tim = 1;
volatile uint8_t toggle_chstat_aux_tim = 1;

//Globals for adc values
float lin_num = 0;
float cur_num = 0;
float op_num = 0;
float swi_num = 0;

float lin_num_aux = 0;
float cur_num_aux = 0;

uint8_t timercounter = 0;

/* USER CODE END PV */

void SystemClock_Config(void);
static void MX_GPIO_Init(void);
static void MX_DMA_Init(void);
static void MX_ADC_Init(void);
static void MX_DAC_Init(void);
static void MX_I2C1_Init(void);
static void MX_USART1_UART_Init(void);
static void MX_TIM2_Init(void);
static void MX_TIM3_Init(void);
static void MX_TIM11_Init(void);
static void MX_TIM9_Init(void);
static void MX_TIM10_Init(void);
static void MX_TIM4_Init(void);
/* USER CODE BEGIN PFP */

void ourInit(void);//Runs several Inits

/* USB Section Begin ---------------------------------------------------------*/
void USB_EXTIinit(void);
void USB_Interrupt_Callback(void);
void EXTI1_IRQHandler(void);
/* USB Section End -----------------------------------------------------------*/

/* ADC Section Begin ---------------------------------------------------------*/
void update_ADC_watchdog(float val);
/* ADC Section End -----------------------------------------------------------*/

/* LCD Section Begin ---------------------------------------------------------*/
void lcd_init (void);   // initialize lcd
void lcd_send_cmd (char cmd);  // send command to the lcd
void lcd_send_data (char data);  // send data to the lcd
void lcd_send_string (char *str);  // send string to the lcd
void lcd_put_cur(int row, int col);  // put cursor at the entered position row (0-3), col (0-19);
void lcd_clear (void);
void LCD_CursorBlinkOnOff( uint8_t cursor_status, uint8_t blink_status );
void lcd_createChar(void);
void lcd_psu_init(void);
void lcd_update_voltage(uint8_t channel, float num);
void lcd_update_amperage(uint8_t channel, float num);
void lcd_psu_update(void);
void lcd_psu_welcome(void);
/* LCD Section End -----------------------------------------------------------*/

/* Keypad Section Begin ------------------------------------------------------*/
void update_keypad(char num);
void clear_keypad(void);
float translate_keypad(void);
uint8_t check_keypad(uint8_t which);
void fill_keypad(uint8_t va, float num);
void keypad_sm(char num);
void row_input(void);
void column_input(void);
void inc_arr_v(int8_t pos);
void inc_arr_a(int8_t pos);
void dec_arr_v(int8_t pos);
void dec_arr_a(int8_t pos);
/* Keypad Section End --------------------------------------------------------*/

/* USER CODE END PFP */

/**
  * @brief  The application entry point.
  * @retval int
  */
int main(void)
{
  /* MCU Configuration--------------------------------------------------------*/

  /* Reset of all peripherals, Initializes the Flash interface and the Systick. */
  HAL_Init();

  /* Configure the system clock */
  SystemClock_Config();

  /* Initialize all configured peripherals */
  MX_GPIO_Init();
  MX_DMA_Init();
  MX_ADC_Init();
  MX_DAC_Init();
  MX_I2C1_Init();
  MX_USART1_UART_Init();
  MX_USB_DEVICE_Init();
  MX_TIM2_Init();
  MX_TIM3_Init();
  MX_TIM11_Init();
  MX_TIM9_Init();
  MX_TIM10_Init();
  MX_TIM4_Init();
  /* USER CODE BEGIN 2 */
  ourInit();
  float error = 0;
  float derivative = 0;
  float integral = 0;
  float error_previous = 0;
  float correction = 0;
  float corrected_volt_set_main;
  uint16_t v1 = 0; // DAC channel 1 is linear
  uint16_t v2 = 375; // DAC channel 2 is switching
  float tmpv1;
  float tmpv2;
  float error_shutdown = 0;
  float derivative_shutdown = 0;
  float integral_shutdown = 0;
  float error_previous_shutdown = 0;
  float correction_shutdown = 0;
  float corrected_volt_set_main_shutdown;


  /* USER CODE END 2 */

  /* Infinite loop */
  /* USER CODE BEGIN WHILE */
  while (1)
  {
    /* USER CODE END WHILE */

    /* USER CODE BEGIN 3 */

	  //Process USB Commands here
	  int8_t tempiter = tailiter;
	  tempiter++;
	  if(tempiter >= CIRCSIZE){
		  tempiter = 0;
	  }
	  //Buffer is not empty
	  if(tempiter != headiter){
			// Measure Voltage
			if ((strncmp("MEAS:VOLT?", (char*)notacircbuff[tempiter], strlen("MEAS:VOLT?")) == 0) ||
					(strncmp("MEASure:VOLTage:DC?", (char*)notacircbuff[tempiter], strlen("MEASure:VOLTage:DC?")) == 0) ||
					(strncmp("MEASure:VOLTage?", (char*)notacircbuff[tempiter], strlen("MEASure:VOLTage?")) == 0)){
				snprintf((char*)MSG, 64, "%.2f, %.2f\n", lin_num_aux, lin_num);
				CDC_Transmit_FS(MSG, strlen((char*)MSG));
				memset(MSG,'\0', 64);
			}
			// Measure Current
			else if ((strncmp("MEAS:CURR?", (char*)notacircbuff[tempiter], strlen("MEAS:CURR?")) == 0) ||
					(strncmp("MEASure:CURRent:DC?", (char*)notacircbuff[tempiter], strlen("MEASure:CURRent:DC?")) == 0) ||
					(strncmp("MEASure:CURRent?", (char*)notacircbuff[tempiter], strlen("MEASure:CURRent?")) == 0)){
				snprintf((char*)MSG, 64, "%.3f, %.3f\n", cur_num_aux, cur_num);
				CDC_Transmit_FS(MSG, strlen((char*)MSG));
				memset(MSG,'\0', 64);
			}
			// CH1 Output Status
			else if ((strncmp("OUTPut:ONE?", (char*)notacircbuff[tempiter], strlen("OUTPut:ONE?")) == 0) ||
					(strncmp("OUTP:ONE?", (char*)notacircbuff[tempiter], strlen("OUTP:ONE?")) == 0)){
				snprintf((char*)MSG, 64, "%d\n", chstat_aux_rx);
				CDC_Transmit_FS(MSG, strlen((char*)MSG));
				memset(MSG,'\0', 64);
			}
			// CH2 Output Status
			else if ((strncmp("OUTPut:TWO?", (char*)notacircbuff[tempiter], strlen("OUTPut:TWO?")) == 0) ||
					(strncmp("OUTP:TWO?", (char*)notacircbuff[tempiter], strlen("OUTP:TWO?")) == 0)){
				snprintf((char*)MSG, 64, "%d\n", chstat_main);
				CDC_Transmit_FS(MSG, strlen((char*)MSG));
				memset(MSG,'\0', 64);
			}
			// CH1 Output ON
			else if ((strncmp("OUTPUT:ONE:START", (char*)notacircbuff[tempiter], strlen("OUTPUT:ONE:START")) == 0) ||
					(strncmp("OUTP:ONE:START", (char*)notacircbuff[tempiter], strlen("OUTP:ONE:START")) == 0)){
				chstat_aux_tx = 1;
				snprintf((char*)MSG, 64, "\n");
				CDC_Transmit_FS(MSG, strlen((char*)MSG));
				memset(MSG,'\0', 64);
			}
			// CH2 Output ON
			else if ((strncmp("OUTPut:TWO:START", (char*)notacircbuff[tempiter], strlen("OUTPut:TWO:START")) == 0) ||
					(strncmp("OUTP:TWO:START", (char*)notacircbuff[tempiter], strlen("OUTP:TWO:START")) == 0)){
				chstat_main = 1;
				snprintf((char*)MSG, 64, "\n");
				CDC_Transmit_FS(MSG, strlen((char*)MSG));
				memset(MSG,'\0', 64);
			}
			// CH1 Output OFF
			else if ((strncmp("OUTPut:ONE:STOP", (char*)notacircbuff[tempiter], strlen("OUTPut:ONE:STOP")) == 0) ||
					(strncmp("OUTP:ONE:STOP", (char*)notacircbuff[tempiter], strlen("OUTP:ONE:STOP")) == 0)){
				chstat_aux_tx = 0;
				snprintf((char*)MSG, 64, "\n");
				CDC_Transmit_FS(MSG, strlen((char*)MSG));
				memset(MSG,'\0', 64);
			}
			// CH2 Output OFF
			else if ((strncmp("OUTPut:TWO:STOP", (char*)notacircbuff[tempiter], strlen("OUTPut:TWO:STOP")) == 0) ||
					(strncmp("OUTP:TWO:STOP", (char*)notacircbuff[tempiter], strlen("OUTP:TWO:STOP")) == 0)){
				chstat_main = 0;
				snprintf((char*)MSG, 64, "\n");
				CDC_Transmit_FS(MSG, strlen((char*)MSG));
				memset(MSG,'\0', 64);
			}
			// CH1 VOLT 1
			else if ((strncmp("VOLTage:ONE:", (char*)notacircbuff[tempiter], strlen("VOLTage:ONE:")) == 0)){
				if ((atof((char*)notacircbuff[tempiter] + strlen("VOLTage:ONE:")) >= 0.00) && (atof((char*)notacircbuff[tempiter] + strlen("VOLTage:ONE:")) <= 12.00)){
					//Truncate voltage inputs to 2 decimal places
					float temp = (float)atof((char*)notacircbuff[tempiter] + 12);
					uint8_t tempbuff[8] = {0};
					snprintf((char*)tempbuff, 8, "%.2f", temp);
					volt_set_aux = (float)atof((char*)tempbuff);
					snprintf((char*)MSG, 64, "\n");
				}
				else{
					snprintf((char*)MSG, 64, "ERROR: INVALID NUMBER\n");
				}
				CDC_Transmit_FS(MSG, strlen((char*)MSG));
				memset(MSG,'\0', 64);
			}
			// CH1 VOLT 2
			else if ((strncmp("VOLT:ONE:", (char*)notacircbuff[tempiter], strlen("VOLT:ONE:")) == 0)){
				if ((atof((char*)notacircbuff[tempiter] + strlen("VOLT:ONE:")) >= 0.00) && (atof((char*)notacircbuff[tempiter] + strlen("VOLT:ONE:")) <= 12.00)){
					//Truncate voltage inputs to 2 decimal places
					float temp = (float)atof((char*)notacircbuff[tempiter] + 9);
					uint8_t tempbuff[8] = {0};
					snprintf((char*)tempbuff, 8, "%.2f", temp);
					volt_set_aux = (float)atof((char*)tempbuff);
					snprintf((char*)MSG, 64, "\n");
				}
				else{
					snprintf((char*)MSG, 64, "ERROR: INVALID NUMBER\n");
				}
				CDC_Transmit_FS(MSG, strlen((char*)MSG));
				memset(MSG,'\0', 64);
			}
			// CH2 VOLT 1
			else if ((strncmp("VOLTage:TWO:", (char*)notacircbuff[tempiter], strlen("VOLTage:TWO:")) == 0)){
				if ((atof((char*)notacircbuff[tempiter] + strlen("VOLTage:TWO:")) >= 0.00) && (atof((char*)notacircbuff[tempiter] + strlen("VOLTage:TWO:")) <= 12.00)){
					//Truncate voltage inputs to 2 decimal places
					float temp = (float)atof((char*)notacircbuff[tempiter] + 12);
					uint8_t tempbuff[8] = {0};
					snprintf((char*)tempbuff, 8, "%.2f", temp);
					volt_set_main_old = volt_set_main;
					volt_set_main = (float)atof((char*)tempbuff);
					snprintf((char*)MSG, 64, "\n");
				}
				else{
					snprintf((char*)MSG, 64, "ERROR: INVALID NUMBER\n");
				}
				CDC_Transmit_FS(MSG, strlen((char*)MSG));
				memset(MSG,'\0', 64);
			}

			// CH2 VOLT 2
			else if ((strncmp("VOLT:TWO:", (char*)notacircbuff[tempiter], strlen("VOLT:TWO:")) == 0)){
				if ((atof((char*)notacircbuff[tempiter] + strlen("VOLT:TWO:")) >= 0.00) && (atof((char*)notacircbuff[tempiter] + strlen("VOLT:TWO:")) <= 12.00)){
					//Truncate voltage inputs to 2 decimal places
					float temp = (float)atof((char*)notacircbuff[tempiter] + 9);
					uint8_t tempbuff[8] = {0};
					snprintf((char*)tempbuff, 8, "%.2f", temp);
					volt_set_main_old = volt_set_main;
					volt_set_main = (float)atof((char*)tempbuff);
					snprintf((char*)MSG, 64, "\n");
				}
				else{
					snprintf((char*)MSG, 64, "ERROR: INVALID NUMBER\n");
				}
				CDC_Transmit_FS(MSG, strlen((char*)MSG));
				memset(MSG,'\0', 64);
			}
			// CH1 AMP 1
			else if ((strncmp("CURRent:ONE:", (char*)notacircbuff[tempiter], strlen("CURRent:ONE:")) == 0)){
				if ((atof((char*)notacircbuff[tempiter] + strlen("CURRent:ONE:")) >= 0.00) && (atof((char*)notacircbuff[tempiter] + strlen("CURRent:ONE:")) <= 0.80)){
					//Truncate amperage inputs to 3 decimal places
					float temp = (float)atof((char*)notacircbuff[tempiter] + 12);
					uint8_t tempbuff[8] = {0};
					snprintf((char*)tempbuff, 8, "%.3f", temp);
					amp_set_aux = (float)atof((char*)tempbuff);
					snprintf((char*)MSG, 64, "\n");
				}
				else{
					snprintf((char*)MSG, 64, "ERROR: INVALID NUMBER\n");
				}
				CDC_Transmit_FS(MSG, strlen((char*)MSG));
				memset(MSG,'\0', 64);
			}
			// CH1 AMP 2
			else if ((strncmp("CURR:ONE:", (char*)notacircbuff[tempiter], strlen("CURR:ONE:")) == 0)){
				if ((atof((char*)notacircbuff[tempiter] + strlen("CURR:ONE:")) >= 0.00) && (atof((char*)notacircbuff[tempiter] + strlen("CURR:ONE:")) <= 0.80)){
					//Truncate amperage inputs to 3 decimal places
					float temp = (float)atof((char*)notacircbuff[tempiter] + 9);
					uint8_t tempbuff[8] = {0};
					snprintf((char*)tempbuff, 8, "%.3f", temp);
					amp_set_aux = (float)atof((char*)tempbuff);
					snprintf((char*)MSG, 64, "\n");
				}
				else{
					snprintf((char*)MSG, 64, "ERROR: INVALID NUMBER\n");
				}
				CDC_Transmit_FS(MSG, strlen((char*)MSG));
				memset(MSG,'\0', 64);
			}

			// CH2 AMP 1
			else if ((strncmp("CURRent:TWO:", (char*)notacircbuff[tempiter], strlen("CURRent:TWO:")) == 0)){
				if ((atof((char*)notacircbuff[tempiter] + strlen("CURRent:TWO:")) >= 0.00) && (atof((char*)notacircbuff[tempiter] + strlen("CURRent:TWO:")) <= 0.80)){
					//Truncate amperage inputs to 3 decimal places
					float temp = (float)atof((char*)notacircbuff[tempiter] + 12);
					uint8_t tempbuff[8] = {0};
					snprintf((char*)tempbuff, 8, "%.3f", temp);
					amp_set_main_old = amp_set_main;
					amp_set_main = (float)atof((char*)tempbuff);
					snprintf((char*)MSG, 64, "\n");
				}
				else{
					snprintf((char*)MSG, 64, "ERROR: INVALID NUMBER\n");
				}
				CDC_Transmit_FS(MSG, strlen((char*)MSG));
				memset(MSG,'\0', 64);
			}

			// CH2 AMP 2
			else if ((strncmp("CURR:TWO:", (char*)notacircbuff[tempiter], strlen("CURR:TWO:")) == 0)){
				if ((atof((char*)notacircbuff[tempiter] + strlen("CURR:TWO:")) >= 0.00) && (atof((char*)notacircbuff[tempiter] + strlen("CURR:TWO:")) <= 0.80)){
					//Truncate amperage inputs to 3 decimal places
					float temp = (float)atof((char*)notacircbuff[tempiter] + 9);
					uint8_t tempbuff[8] = {0};
					snprintf((char*)tempbuff, 8, "%.3f", temp);
					amp_set_main_old = amp_set_main;
					amp_set_main = (float)atof((char*)tempbuff);
					snprintf((char*)MSG, 64, "\n");
				}
				else{
					snprintf((char*)MSG, 64, "ERROR: INVALID NUMBER\n");
				}
				CDC_Transmit_FS(MSG, strlen((char*)MSG));
				memset(MSG,'\0', 64);
			}
			// Identify
			else if ((strncmp("*IDN?", (char*)notacircbuff[tempiter], strlen("*IDN?")) == 0)){
				CDC_Transmit_FS((uint8_t*)"493 Lab Power Supply\n", strlen("493 Lab Power Supply\n"));
			}
			//Ignore read, we can add it back later if needed
			else if ((strncmp("READ?", (char*)notacircbuff[tempiter], strlen("READ?")) == 0)){
				//CDC_Transmit_FS(MSG, strlen((char*)MSG));
				//memset(MSG,'\0', 64);
				CDC_Transmit_FS((uint8_t*)"\n", strlen("\n"));
			}
			// Invalid input/command not supported
			else{
				snprintf((char*)MSG, 64, "ERROR: INVALID COMMAND\n");
				CDC_Transmit_FS(MSG, strlen((char*)MSG));
				memset(MSG,'\0', 64);
			}
			memset (notacircbuff[tempiter], '\0', 64); // clear the buffer
			tailiter++;
			if(tailiter >= CIRCSIZE){
				tailiter = 0;
			}
	  }


	  //Control channel here

	  op_num_old = (float)op_num;

	  uint16_t vrefvalue = (uint16_t) *vrefptr;
	  float vddcalc = (float)3.0 * ((float)vrefvalue / (float)ADC_VREF);

	  float cur_num_temp = ((((float)3.0 * (float)ADC_CURRENT * (float)vrefvalue)/((float)ADC_VREF * (float)4095) / (float)20) / (float)0.15);
	  cur_num  = (cur_num_temp >= 0.0000) ? cur_num_temp : 0.0000;

	  float op_num_temp = ((float)3.0 * ((float)ADC_OPAMP * (float)4.0) * (float)vrefvalue)/((float)ADC_VREF * (float)4095) - ((float)cur_num * (float)0.35);
	  op_num  = (op_num_temp >= 0.0000) ? op_num_temp : 0.0000;

	  float lin_num_temp = ((float)3.0 * ((float)ADC_LINEAR * (float)4.0) * (float)vrefvalue)/((float)ADC_VREF * (float)4095) - ((float)cur_num * (float)0.35);
	  lin_num  = (lin_num_temp >= 0.0000) ? lin_num_temp : 0.0000;

	  float swi_num_temp = ((float)3.0 * ((float)ADC_SWITCHING * (float)5.0) * (float)vrefvalue)/((float)ADC_VREF * (float)4095);
	  swi_num  = (swi_num_temp >= 0.0000) ? swi_num_temp : 0.0000;

	  //PID
	  if (chstat_main) {
		  error = (float)lin_num - (float)volt_set_main;
		  integral += (float)error;
		  if (integral > (float)4095.0) {
			  integral = (float)4095;
		  } else if (integral < (float)(-4095.0)) {
			  integral = (float)(-4095.0);
		  }
		  derivative = (float)error - (float)error_previous;
		  error_previous = (float)error;
		  correction = ((float)P * (float)error) + ((float)I * (float)integral) + ((float)D * (float)derivative);
		  corrected_volt_set_main = (float)volt_set_main - (float)correction;
		  tmpv1 = ((((float)corrected_volt_set_main / (float)4.0) + ((float)1.0 / (float)4.0)) * (float)4095) / (float)vddcalc;
		  if (tmpv1 >= 4094) {
			  tmpv1 = 4094;
		  } else if (tmpv1 < 0) {
			  tmpv1 = 1;
		  }
		  v1 = (uint16_t) tmpv1;
	  } else {
		  error_shutdown = op_num - volt_set_main;
		  integral_shutdown += error_shutdown;
		  if (integral_shutdown > (float)4095.0) {
			  integral_shutdown = (float)4095;
		  } else if (integral_shutdown < (float)-4095.0) {
			  integral_shutdown = (float)-4095.0;
		  }
		  derivative_shutdown = error_shutdown - error_previous_shutdown;
		  error_previous_shutdown = error_shutdown;
		  correction_shutdown = P * error_shutdown + I * integral_shutdown + D * derivative_shutdown;
		  corrected_volt_set_main_shutdown = volt_set_main - correction_shutdown;
		  tmpv1 = (((((float)corrected_volt_set_main_shutdown / (float)4.0) + ((float)1.0 / (float)4.0)) * (float)4095) / (float)vddcalc);
		  if (tmpv1 > 4095) {
			  tmpv1 = 4095;
		  } else if (tmpv1 < 0) {
			  tmpv1 = 0;
		  }
		  v1 = (uint16_t) tmpv1;
	  }
	  HAL_DAC_SetValue(&hdac, DAC_CHANNEL_1, DAC_ALIGN_12B_R, v1);
//	  */

	  /*
	   * The calculation we do to determine what we need to set the dac for the switching regulator to is determined by the following formula
	   * 1.235 = (R3*R2*Vout + R1*R2Vdac) / (R3*R2 + R1*R3 + R1*R2) where R1 = 10k, R2 = 1.2k, R3 = 2K
	   * This equation would be a little cumbersome to calculate every time we loop so I have simplified it on paper to the following formula
	   * Vdac = 3.5403 - 0.2*Vout; ) 46.5183 = Vout + 5Vdac
	   */
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

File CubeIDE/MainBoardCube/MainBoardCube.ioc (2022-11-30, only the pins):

Mcu.UserName=STM32L152RBTxA
PA0-WKUP1.Signal=ADC_IN0
PA1.Signal=ADC_IN1
PA10.Signal=USART1_RX
PA11.Signal=USB_DM
PA12.Signal=USB_DP
PA13.Signal=SYS_JTMS-SWDIO
PA14.Signal=SYS_JTCK-SWCLK
PA15.GPIO_Label=Unused_Pin_11
PA15.Signal=GPIO_Input
PA2.Signal=ADC_IN2
PA3.Signal=ADC_IN3
PA4.Signal=COMP_DAC1_group
PA5.Signal=COMP_DAC2_group
PA6.GPIO_Label=Channel Shutdown
PA6.Signal=GPIO_Output
PA7.GPIO_Label=Unused_Pin_8
PA7.Signal=GPIO_Input
PA8.GPIO_Label=Unused_Pin_10
PA8.Signal=GPIO_Input
PA9.Signal=USART1_TX
PB0.GPIO_Label=Rot_CLK
PB0.Signal=GPXTI0
PB1.GPIO_Label=Rot_DT
PB1.Signal=GPIO_Input
PB10.GPIO_Label=Row_1
PB10.Signal=GPXTI10
PB11.GPIO_Label=Row_2
PB11.Signal=GPXTI11
PB12.GPIO_Label=Row_3
PB12.Signal=GPXTI12
PB13.GPIO_Label=Row_4
PB13.Signal=GPXTI13
PB14.GPIO_Label=Row_5
PB14.Signal=GPXTI14
PB15.GPIO_Label=Unused_Pin_9
PB15.Signal=GPIO_Input
PB2.GPIO_Label=Rot_SW
PB2.Signal=GPXTI2
PB3.GPIO_Label=Unused_Pin_16
PB3.Signal=GPIO_Input
PB4.GPIO_Label=Unused_Pin_17
PB4.Signal=GPIO_Input
PB5.GPIO_Label=Unused_Pin_18
PB5.Signal=GPIO_Input
PB6.Signal=I2C1_SCL
PB7.Signal=I2C1_SDA
PB8.GPIO_Label=Unused_Pin_19
PB8.Signal=GPIO_Input
PB9.GPIO_Label=Unused_Pin_20
PB9.Signal=GPIO_Input
PC0.GPIO_Label=Unused_Pin_4
PC0.Signal=GPIO_Input
PC1.GPIO_Label=Unused_Pin_5
PC1.Signal=GPIO_Input
PC10.GPIO_Label=Unused_Pin_12
PC10.Signal=GPIO_Input
PC11.GPIO_Label=Unused_Pin_13
PC11.Signal=GPIO_Input
PC12.GPIO_Label=Unused_Pin_14
PC12.Signal=GPIO_Input
PC13-WKUP2.GPIO_Label=Unused_Pin_1
PC13-WKUP2.Signal=GPIO_Input
PC14-OSC32_IN.GPIO_Label=Unused_Pin_2
PC14-OSC32_IN.Signal=GPIO_Input
PC15-OSC32_OUT.GPIO_Label=Unused_Pin_3
PC15-OSC32_OUT.Signal=GPIO_Input
PC2.GPIO_Label=Unused_Pin_6
PC2.Signal=GPIO_Input
PC3.GPIO_Label=Unused_Pin_7
PC3.Signal=GPIO_Input
PC4.GPIO_Label=Status_LED_1
PC4.Signal=GPIO_Output
PC5.GPIO_Label=Status_LED_2
PC5.Signal=GPIO_Output
PC6.GPIO_Label=Col_1
PC6.Signal=GPIO_Output
PC7.GPIO_Label=Col_2
PC7.Signal=GPIO_Output
PC8.GPIO_Label=Col_3
PC8.Signal=GPIO_Output
PC9.GPIO_Label=Col_4
PC9.Signal=GPIO_Output
PD2.GPIO_Label=Unused_Pin_15
PD2.Signal=GPIO_Input
PH0-OSC_IN.Signal=RCC_OSC_IN
PH1-OSC_OUT.Signal=RCC_OSC_OUT

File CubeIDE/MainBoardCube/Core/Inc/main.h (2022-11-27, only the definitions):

#define Unused_Pin_1_Pin GPIO_PIN_13
#define Unused_Pin_1_GPIO_Port GPIOC
#define Unused_Pin_2_Pin GPIO_PIN_14
#define Unused_Pin_2_GPIO_Port GPIOC
#define Unused_Pin_3_Pin GPIO_PIN_15
#define Unused_Pin_3_GPIO_Port GPIOC
#define Unused_Pin_4_Pin GPIO_PIN_0
#define Unused_Pin_4_GPIO_Port GPIOC
#define Unused_Pin_5_Pin GPIO_PIN_1
#define Unused_Pin_5_GPIO_Port GPIOC
#define Unused_Pin_6_Pin GPIO_PIN_2
#define Unused_Pin_6_GPIO_Port GPIOC
#define Unused_Pin_7_Pin GPIO_PIN_3
#define Unused_Pin_7_GPIO_Port GPIOC
#define Channel_Shutdown_Pin GPIO_PIN_6
#define Channel_Shutdown_GPIO_Port GPIOA
#define Unused_Pin_8_Pin GPIO_PIN_7
#define Unused_Pin_8_GPIO_Port GPIOA
#define Status_LED_1_Pin GPIO_PIN_4
#define Status_LED_1_GPIO_Port GPIOC
#define Status_LED_2_Pin GPIO_PIN_5
#define Status_LED_2_GPIO_Port GPIOC
#define Rot_CLK_Pin GPIO_PIN_0
#define Rot_CLK_GPIO_Port GPIOB
#define Rot_CLK_EXTI_IRQn EXTI0_IRQn
#define Rot_DT_Pin GPIO_PIN_1
#define Rot_DT_GPIO_Port GPIOB
#define Rot_SW_Pin GPIO_PIN_2
#define Rot_SW_GPIO_Port GPIOB
#define Rot_SW_EXTI_IRQn EXTI2_IRQn
#define Row_1_Pin GPIO_PIN_10
#define Row_1_GPIO_Port GPIOB
#define Row_1_EXTI_IRQn EXTI15_10_IRQn
#define Row_2_Pin GPIO_PIN_11
#define Row_2_GPIO_Port GPIOB
#define Row_2_EXTI_IRQn EXTI15_10_IRQn
#define Row_3_Pin GPIO_PIN_12
#define Row_3_GPIO_Port GPIOB
#define Row_3_EXTI_IRQn EXTI15_10_IRQn
#define Row_4_Pin GPIO_PIN_13
#define Row_4_GPIO_Port GPIOB
#define Row_4_EXTI_IRQn EXTI15_10_IRQn
#define Row_5_Pin GPIO_PIN_14
#define Row_5_GPIO_Port GPIOB
#define Row_5_EXTI_IRQn EXTI15_10_IRQn
#define Unused_Pin_9_Pin GPIO_PIN_15
#define Unused_Pin_9_GPIO_Port GPIOB
#define Col_1_Pin GPIO_PIN_6
#define Col_1_GPIO_Port GPIOC
#define Col_2_Pin GPIO_PIN_7
#define Col_2_GPIO_Port GPIOC
#define Col_3_Pin GPIO_PIN_8
#define Col_3_GPIO_Port GPIOC
#define Col_4_Pin GPIO_PIN_9
#define Col_4_GPIO_Port GPIOC
#define Unused_Pin_10_Pin GPIO_PIN_8
#define Unused_Pin_10_GPIO_Port GPIOA
#define Unused_Pin_11_Pin GPIO_PIN_15
#define Unused_Pin_11_GPIO_Port GPIOA
#define Unused_Pin_12_Pin GPIO_PIN_10
#define Unused_Pin_12_GPIO_Port GPIOC
#define Unused_Pin_13_Pin GPIO_PIN_11
#define Unused_Pin_13_GPIO_Port GPIOC
#define Unused_Pin_14_Pin GPIO_PIN_12
#define Unused_Pin_14_GPIO_Port GPIOC
#define Unused_Pin_15_Pin GPIO_PIN_2
#define Unused_Pin_15_GPIO_Port GPIOD
#define Unused_Pin_16_Pin GPIO_PIN_3
#define Unused_Pin_16_GPIO_Port GPIOB
#define Unused_Pin_17_Pin GPIO_PIN_4
#define Unused_Pin_17_GPIO_Port GPIOB
#define Unused_Pin_18_Pin GPIO_PIN_5
#define Unused_Pin_18_GPIO_Port GPIOB
#define Unused_Pin_19_Pin GPIO_PIN_8
#define Unused_Pin_19_GPIO_Port GPIOB
#define Unused_Pin_20_Pin GPIO_PIN_9
#define Unused_Pin_20_GPIO_Port GPIOB

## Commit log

2022-09-05 Adding the KiCad Project
    [LabPowerSupply.kicad_pcb, LabPowerSupply.kicad_sch]
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2022-09-07 Revert "Merge branch 'cubemx' into 'main'"
    This reverts merge request !2
    [ProtoTest.ioc, main.c, main.h]
2022-09-07 Revert "Removed 'Symbols and Footprints'"
    This reverts commit e7743ccdda4055fcc0b5b6e679da1c1eaa64735f
2022-09-07 Fixing my screwup
    [LabPowerSupply.kicad_sch]
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2022-09-14 Added microcontrollers to schematic
    [LabPowerSupply.kicad_sch]
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2022-09-15 Fixed keypad entry bug when no leading 0 is entered
    [main.c]
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2022-09-19 Finished first pass on the schematic
    [BridgeRectifier.kicad_sch, Channel1PowerRails.kicad_sch, Channel2_3V3VoltRail.kicad_sch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]
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2022-09-28 Resistor footprints changed to 0603
    [BridgeRectifier.kicad_sch, Channel1PowerRails.kicad_sch, Channel2_3V3VoltRail.kicad_sch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]
2022-09-28 Changed capacitor footprints, added resistor and diode to linear
    [Channel1PowerRails.kicad_sch, LabPowerSupply.kicad_pcb, LabPowerSupply.kicad_sch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]
2022-09-28 Added mcu capacitors, split 5v inductors
    [BridgeRectifier.kicad_sch, Channel1PowerRails.kicad_sch, Channel2_3V3VoltRail.kicad_sch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]
2022-09-28 Added oscillator to mcu2
    [DifferentialOpAmpCircuit.kicad_sch, LabPowerSupply.kicad_pcb, LabPowerSupply.kicad_sch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]
2022-09-28 Fixed mcu supply
    [PrimaryController.kicad_sch, SecondaryController.kicad_sch]
2022-09-30 Fixed 5v/3v regulators, fixed switching regulator comp
    [Channel1PowerRails.kicad_sch, Channel2_3V3VoltRail.kicad_sch, LabPowerSupply.kicad_pcb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]
2022-09-30 Finished grouping regulator 'modules'
    [LabPowerSupply.kicad_pcb]
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2022-09-30 Made oscillator caps smd
    [LabPowerSupply.kicad_pcb, LabPowerSupply.kicad_sch, NoConnect.kicad_sch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]
2022-09-30 fixed linear cap footprints
    [LabPowerSupply.kicad_pcb, LabPowerSupply.kicad_sch, LinearVoltageRegulator.kicad_sch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]
2022-09-30 Changed most parts to smd
    [BridgeRectifier.kicad_sch, Channel1PowerRails.kicad_sch, Channel2_3V3VoltRail.kicad_sch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]
2022-10-02 Fixed oscillator caps, began changing resistors to more common values
    [ChargePump.kicad_sch, LabPowerSupply.kicad_pcb, LabPowerSupply.kicad_sch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]
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2022-10-03 Changed capacitors to x7r
    [Channel1PowerRails.kicad_sch, Channel2_3V3VoltRail.kicad_sch, ChargePump.kicad_sch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]
2022-10-03 Fixed cap footprints
    [Channel1PowerRails.kicad_sch, Channel2_3V3VoltRail.kicad_sch, LabPowerSupply.kicad_pcb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]
2022-10-03 SMD Oscillator
    [ChargePump.kicad_sch, LabPowerSupply.kicad_pcb, LabPowerSupply.kicad_sch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]
2022-10-04 removed transformer and bug squached
    [FrontPanel.kicad_sch, LabPowerSupply.kicad_pcb, LabPowerSupply.kicad_sch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]
2022-10-05 Changed grid size, began regrouping
    [Channel1PowerRails.kicad_sch, Channel2_3V3VoltRail.kicad_sch, LabPowerSupply.kicad_pcb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]
2022-10-05 Finished grouping regulation parts
    [LabPowerSupply.kicad_pcb, LinearVoltageRegulator.kicad_sch]
2022-10-05 Added the Front Panel Project
    [FrontPanel.kicad_pcb, FrontPanel.kicad_sch, LabPowerSupply.kicad_pcb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]
2022-10-05 Fixed button footprints
    [FrontPanel.kicad_pcb, FrontPanel.kicad_sch]
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2022-10-05 Remove/hide duplicate references, place values on silkscreen
    [FrontPanel.kicad_pcb, LabPowerSupply.kicad_pcb]
2022-10-05 Place 3.3 and 5v on bottom
    [LabPowerSupply.kicad_pcb]
2022-10-06 Fixed 3.3v footprint
    [Channel1PowerRails.kicad_sch, Channel2_3V3VoltRail.kicad_sch, LabPowerSupply.kicad_pcb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]
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2022-10-07 Figured out how to make fill zones
    [LabPowerSupply.kicad_pcb, LabPowerSupply.kicad_sch, PrimaryController.kicad_sch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]
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2022-10-08 Fixed current sense and static modules
    [CurrentSense.kicad_sch, LabPowerSupply.kicad_pcb, LabPowerSupply.kicad_sch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]
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2022-10-12 Fix front panel and routed main regulator
    [FrontPanel.kicad_pcb, FrontPanel.kicad_sch, LabPowerSupply.kicad_pcb]
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2022-10-13 Front panel routing and edge cut
    [FrontPanel.kicad_pcb]
2022-10-13 Front panel routing done, drc only shows silkscreen warnings
    [FrontPanel.kicad_pcb]
2022-10-13 Rerouted front panel with less vias
    [FrontPanel.kicad_pcb, FrontPanel.kicad_sch]
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2022-10-13 Copied channel module positions other than linear
    [LabPowerSupply.kicad_pcb]
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2022-10-14 Alligned trace grid on front panel
    [FrontPanel.kicad_pcb]
2022-10-14 Fixed MCU communication pins and optocoupler
    [LabPowerSupply.kicad_pcb, LabPowerSupply.kicad_sch, LinearVoltageRegulator.kicad_sch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]
2022-10-14 Ground and power planes
    [LabPowerSupply.kicad_pcb]
2022-10-15 Began restructure on ch2
    [LabPowerSupply.kicad_pcb]
2022-10-15 Began linear rework
    [LabPowerSupply.kicad_pcb]
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2022-10-17 Finialized the Front Panel
    [FrontPanel.kicad_pcb]
2022-10-17 Finialize Front Panel for realz
    [FrontPanel.kicad_pcb]
2022-10-17 Finialize the Front Panel for realz for realz
    [FrontPanel.kicad_pcb]
2022-10-17 Finalized Front Panel for realz for realz for realz
    [FrontPanel.kicad_pcb]
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2022-10-18 Copy ch2 config to ch1
    [LabPowerSupply.kicad_pcb, LabPowerSupply.kicad_sch]
2022-10-18 Copied ch2 traces and fills, nets still need to be checked
    [LabPowerSupply.kicad_pcb]
2022-10-18 Fixed most nets, may require additional checking
    [LabPowerSupply.kicad_pcb]
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2022-10-20 Started ch2 MCU routing
    [LabPowerSupply.kicad_pcb, LabPowerSupply.kicad_sch, PrimaryController.kicad_sch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]
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2022-10-21 Reduced ch1 height slightly
    [LabPowerSupply.kicad_pcb]
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2022-10-24 Adding 3D printing stuff
    [button_cap.FCStd, button_cap_base.stl, spacer.scad]
2022-10-24 changed pin socket to header
    [LabPowerSupply.kicad_pcb]
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2022-10-24 Got the CAD model for the button caps working
    [button_cap.FCStd, spacer.scad]
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2022-10-29 Still owkring on the 3D models
    [0-button_cap-Base.stl, 0-button_cap-Label.stl, button_cap.FCStd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]
2022-10-29 Added Front Panel Switch to the parts list
    [Part List.xlsx]
2022-10-30 Cleaned up the git repo
    [0-button_cap-Base.stl, 0-button_cap-Label.stl, button_cap.FCStd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]
2022-10-30 Added models for all of the buttons
    [button_cap-0.stl, button_cap-1.stl, button_cap-2.stl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]
2022-10-30 fixed button caps
    [button_cap-0.stl, button_cap-1.stl, button_cap-2.stl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]
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2022-10-31 updated 3D models again
    [button_cap-A1.stl, button_cap-A2.stl, button_cap-V1.stl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]
2022-11-02 New Button Caps Model
    [ButtonCap.scad, ButtonCap0.stl, ButtonCap1.stl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]
2022-11-02 Changed from 4 balls to 8
    [ButtonCap.scad]
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2022-11-03 Got a model that actually works
    [ButtonCap.scad]
2022-11-04 made spacer plate or the front panel
    [ButtonCap.scad, FrontPanelSpacerPlate.scad, button_cap-0.stl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]
2022-11-07 Got a working prototype of the front panel spacer
    [ButtonCap.scad, FrontPanelSpacerPlate.scad, FrontPanelSpacerPlate.stl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]
2022-11-09 Pull for the gimp file
    [FrontPanelSpacerPlate.scad, FrontPanelSpacerPlate.stl, spacer.scad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]
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2022-11-14 New Front Panel Design
    [ButtonCap.scad, FrontPanelSpacerPlate.scad, FrontPanelSpacerPlate.stl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]
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2022-11-17 Fixed the Beautified Schematics
    [Channel1PowerRails.kicad_sch, LabPowerSupply.kicad_sch, LinearVoltageRegulator.kicad_sch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]
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2022-11-18 Updating the 3D printing files
    [ButtonCap.scad, FrontPanelSpacerPlate.scad, FrontPanelSpacerPlate.stl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]
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2022-11-19 Changed symbols to actual MOSFETs
    [5-3V3Rails.kicad_sch, LabPowerSupply.kicad_sch, LinearVoltageRegulator.kicad_sch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]
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2022-11-24 Added clamping to the integral term to prevent windup
    [main.c]
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2022-11-26 Added current limits, added channel button control, added switching regulator control, reverted to bangbang on linear for now, optimized uart slightly
    [MainBoardCube.ioc, SecondaryBoardCube.ioc, main.c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]
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2022-11-26 Pushing broken encoder code for review
    [MainBoardCube.ioc, main.c]
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2022-11-27 Added welcome message, pulled down unused pins, removed offset from opamp control to prevent overshooting
    [MainBoardCube.ioc, SecondaryBoardCube.ioc, main.c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]
2022-11-28 Update part list, added SCPI code from Dean, made a lazy circular buffer for usb commands
    [Alternate Part List.xlsx]
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2022-12-01 Added plots for voltage and current error along with their data and scripts
    [0.00A Voltage.csv, 0.04A Voltage.csv, 0.08A Voltage.csv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]
2022-12-02 final commit from Tarun
    [0.00A Voltage.csv, 0.04A Voltage.csv, 0.08A Voltage.csv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]

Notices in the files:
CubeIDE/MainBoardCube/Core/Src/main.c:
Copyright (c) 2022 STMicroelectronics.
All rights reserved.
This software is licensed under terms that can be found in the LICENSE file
